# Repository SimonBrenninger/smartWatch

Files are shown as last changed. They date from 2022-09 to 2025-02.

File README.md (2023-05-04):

# smartWatch

is a simple, digital wristwatch that uses LEDs to indicate the position of each clock arm.

## Smart Features

The smartWatch incorporates an nRF52810 for handling BLE connectivity to send the monitored data regularly to the host device.

## PCB Design

The PCB was designed using [KiCad](https://kicad.org).

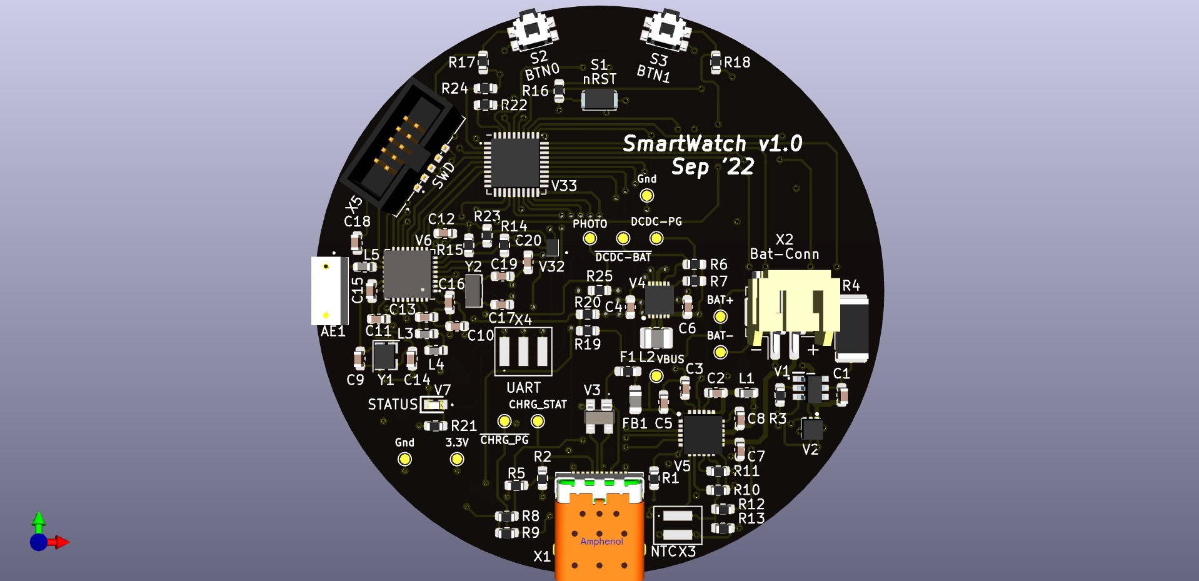
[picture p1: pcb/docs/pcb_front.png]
PCB render front-side

PCB front-side

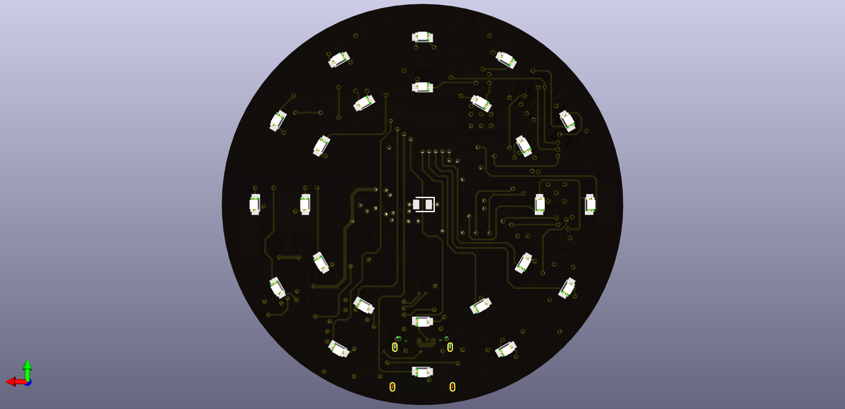
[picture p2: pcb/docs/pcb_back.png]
PCB render back-side

PCB back-side

## Future Features

A future revision will include a biomedical sensor to enable even more smart functionalities i.e. SpO2 and heart-rate measurements.

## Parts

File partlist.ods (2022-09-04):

smartWatch | BOM |  |  |  |  |  | 30cm pcb
Name | Qty | Mouser No: | Mfr. No: | Total Price | Datasheet | Alternatives
nRF52810 | 1 | 949-NRF52810-QFAA-T | nRF52810-QFAA-T (https://www.mouser.at/ProductDetail/Nordic-Semiconductor/nRF52810-QFAA-T?qs=gt1LBUVyoHlzDk3rt9zm6Q%3D%3D) | 3.33 | nRF52810-QFAA-T (https://www.mouser.at/datasheet/2/297/nRF52810_PB_v1.1-1146849.pdf)
Phototransistor | 1 | SFH 3710-Z | SFH 3710-Z (https://www.mouser.at/ProductDetail/ams-OSRAM/SFH-3710-Z?qs=K5ta8V%252BWhtbrxZMXxkWWCQ%3D%3D) | 0.9 | SFH 3710-Z (https://dammedia.osram.info/media/resource/hires/osram-dam-5961394/SFH%203710_EN.pdf)
I/O Expander | 1 | PCA9957HNMP | PCA9957HNMP (https://www.mouser.at/ProductDetail/NXP-Semiconductors/PCA9957HNMP?qs=Cb2nCFKsA8p1S9uEv3UAJg%3D%3D) | 2.61 | PCA9957HNMP (https://www.mouser.at/datasheet/2/302/PCA9957DS-1670403.pdf) |  | I2C (+INT) |  | INT any edge on any pin
Gyroscope | 1 | 438-MXC4005XC | MXC4005XC (https://www.mouser.at/ProductDetail/MEMSIC/MXC4005XC?qs=RcG8xmE7yp3iyYgWLmAtUw%3D%3D) | 1.42 | MXC4005XC (https://www.mouser.at/datasheet/2/821/Memsic_08302019_MXC400xXC_Datasheet_Rev_B-1892039.pdf) |  | I2C + INT |  | INT Shake-Detection
Protection | 1 | 621-AP9101CAK6ABTRG1 | AP9101CAK6-ABTRG1 (https://www.mouser.at/ProductDetail/Diodes-Incorporated/AP9101CAK6-ABTRG1?qs=W66WzN12R3Y9HS2QV9IuJA%3D%3D) | 0.44 | AP9101CAK6-ABTRG1 (https://www.mouser.at/datasheet/2/115/DIOD_S_A0007229744_1-2542938.pdf) | XB8089D
Charger | 1 | BQ25606RGET | BQ25606RGET (https://www.mouser.at/ProductDetail/Texas-Instruments/BQ25606RGET?qs=5aG0NVq1C4yFkgOQCbyUyg%3D%3D) | 3.99 | BQ25606RGET (https://www.ti.com/general/docs/suppproductinfo.tsp?distId=26&gotoUrl=https://www.ti.com/lit/gpn/bq25606) | BQ24092DGQR | CHG +PG |  | Charge done, power good
eFuse | 1 | 757-TCKE812NA,RF | TCKE812NA,RF (https://www.mouser.at/ProductDetail/Toshiba/TCKE812NARF?qs=7MVldsJ5UazIz%2F5VEH%2F60g%3D%3D) | 1.48 | TCKE812NA,RF (https://www.mouser.at/datasheet/2/408/TCKE812NA_datasheet_en_20210705-2509738.pdf) | TPS259621, 595-TPS25200QDRVRQ1
DC-DC | 1 | 968-ISL9110IRT7Z-T7A | ISL9110IRT7Z-T7A (https://www.mouser.at/ProductDetail/Renesas-Intersil/ISL9110IRT7Z-T7A) | 2.8 | ISL9110IRT7Z-T7A (https://www.mouser.at/datasheet/2/698/REN_isl9110_12_DST_20050421-1529440.pdf) | TPS61085DGKR | PG + BAT |  | Output & input power-good
ESD | 1 | 576-SP0503BAHTG | SP0503BAHTG (https://eu.mouser.com/ProductDetail/Littelfuse/SP0503BAHTG?qs=uD%2FdkN7XIa0NTYXwHdELYA%3D%3D) | 0.89 | SP0503BAHTG (https://eu.mouser.com/datasheet/2/240/Littelfuse_TVS_Diode_Array_SP05_Datasheet_pdf-777043.pdf)
LEDs green | 24 | 710-150080GS75000 | 150080GS75000 (https://www.mouser.at/ProductDetail/Wurth-Elektronik/150080GS75000?qs=2kOmHSv6VfQRoTEZVk1mGA%3D%3D) | 0.19 | 150080GS75000 (https://www.mouser.at/datasheet/2/445/150080GS75000-1715657.pdf)
LED red | 1 | 710-150060SS75003 | 150060SS75003 (https://www.mouser.at/ProductDetail/Wurth-Elektronik/150060SS75003?qs=Li%252BoUPsLEntNiRmIe%252Bnzlg%3D%3D) | 0.33 | 150060SS75003 (https://www.mouser.at/datasheet/2/445/150060SS75003-2907500.pdf)
MOSFET | 1 | 757-SSM6N68NULF | SSM6N68NU,LF (https://eu.mouser.com/ProductDetail/Toshiba/SSM6N68NULF?qs=wUXugUrL1qwp%2FrzVtV%2F87w%3D%3D) | 0.47 | SSM6N68NU,LF (https://eu.mouser.com/datasheet/2/408/SSM6N68NU_datasheet_en_20210107-1358562.pdf)
Thermistor NTC | 1 | 103AT-2 | 103AT-2 (https://www.mouser.at/ProductDetail/Semitec/103AT-2?qs=wgO0AD0o1vvcDzsKguD%252Bew%3D%3D) | 0.97 | 103AT-2 (https://www.mouser.at/datasheet/2/362/semitec_atthermistor-1202913.pdf)
USB-C | 1 | 12401598E4#2A | 12401598E4#2A (https://www.mouser.at/ProductDetail/Amphenol-Commercial-Products/12401598E42A?qs=367PjNmvCmllVMBVyIyS3w%3D%3D) | 1.58 | 12401598E4#2A (https://www.amphenol-icc.com/media/wysiwyg/files/documentation/datasheet/inputoutput/io_usb_type_c.pdf)
USB-Breakout |  |  | 4396 (https://www.mouser.at/ProductDetail/Adafruit/4396?qs=CUBnOrq4ZJwQuAtZPG3t1A%3D%3D) | 3.5
Antenna | 1 | NN01-102 | NN01-102 (https://www.mouser.at/ProductDetail/Ignion/NN01-102?qs=bAKSY%2FctAC74AFavC%252BjOHQ%3D%3D) | 0.68 | NN01-102 (https://www.mouser.at/datasheet/2/1029/Ignion_03262021_NN01_102-2255879.pdf) | https://www.ignion.io/files/UM_NN01-102.pdf
32MHz | 1 | ECS-320-8-36CKM-TR3 | ECS-320-8-36CKM-TR3 (https://www.mouser.at/ProductDetail/ECS/ECS-320-8-36CKM-TR3) | 0.36 | ECS-320-8-36CKM-TR3 (https://www.mouser.at/datasheet/2/122/ECX_2236-2497269.pdf)
32k | 1 | ECS-.327-9-34B-C-TR | ECS-.327-9-34B-C-TR (https://www.mouser.at/ProductDetail/ECS/ECS-.327-9-34B-C-TR?qs=wo4x%252BUeoG8W%2FQAwbzhP8Uw%3D%3D) | 0.78 | ECS-.327-9-34B-C-TR (https://www.mouser.at/datasheet/2/122/ecx-31b-1108368.pdf)
JST PH | 2 |  | S2B-PH-SM4 (https://lcsc.com/product-detail/Wire-To-Board-Wire-To-Wire-Connector_JST-Sales-America-S2B-PH-SM4-TB-LF-SN_C295747.html)
Health Sensor | 1 | 985-AS7038RB-COLM | AS7038RB-COLM (https://www.mouser.at/ProductDetail/ams/AS7038RB-COLM?qs=sPbYRqrBIVlfIQI2Rxv0lA%3D%3D) | 3.58 | AS7038RB-COLM (https://www.mouser.at/datasheet/2/588/AS7038RB_DS000726_2_00-1903063.pdf) |  | https://ams.com/documents/20143/36005/AS7038GB_AS7038RB_PD000546_1-00.pdf/9ac1d968-28da-d224-bd64-31765c393177
 |  |  |  |  |  |  | LTC3440EMS#TRPBF (https://www.mouser.at/ProductDetail/Analog-Devices/LTC3440EMSTRPBF?qs=hVkxg5c3xu9HFklrpLlQPw%3D%3D) | TPS54231DR (https://www.mouser.at/ProductDetail/Texas-Instruments/TPS54231DR?qs=XGzIaZb%2FFYKibJTOhGUd1A%3D%3D)
 |  | 0.2mm stencil

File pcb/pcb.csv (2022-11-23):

Source: | /home/simon/Documents/hardware_dev/projects/smartWatch/pcb/pcb.kicad_sch
Date: | Tue 01 Nov 2022 13:50:42 CET
Tool: | Eeschema 6.0.8+dfsg-1~bpo11+1
Generator: | /usr/share/kicad/plugins/bom_csv_grouped_by_value_with_fp.py
Component Count: | 108
Ref | Qnty | Value | Cmp name | Footprint | Description | Vendor
AE1, | 1 | Antenna_Chip | Antenna | myLib:Ignion_NN01-102_BT_WIFI | Antenna
C1, C11, C12, C16, | 4 | 100n | C_Small | Capacitor_SMD:C_0603_1608Metric | Unpolarized capacitor, small symbol
C2, C10, C20, | 3 | 4u7 | C_Small | Capacitor_SMD:C_0603_1608Metric | Unpolarized capacitor, small symbol
C3, C4, C6, C7, C8, | 5 | 10u | C_Small | Capacitor_SMD:C_0603_1608Metric | Unpolarized capacitor, small symbol
C5, C13, | 2 | 1u | C_Small | Capacitor_SMD:C_0603_1608Metric | Unpolarized capacitor, small symbol
C9, C14, C17, C19, | 4 | 12p | C_Small | Capacitor_SMD:C_0603_1608Metric | Unpolarized capacitor, small symbol
C15, | 1 | 100p | C_Small | Capacitor_SMD:C_0603_1608Metric | Unpolarized capacitor, small symbol
C18, | 1 | 0.8p | C_Small | Capacitor_SMD:C_0603_1608Metric | Unpolarized capacitor, small symbol
F1, | 1 | Fuse_1A | Fuse_Small | Fuse:Fuse_0603_1608Metric_Pad1.05x0.95mm_HandSolder | Fuse, small symbol
FB1, | 1 | FerriteBead_Small | FerriteBead_Small | Inductor_SMD:L_0805_2012Metric | Ferrite bead, small symbol
L1, | 1 | 1u | L_Small | Inductor_SMD:L_0603_1608Metric | Inductor, small symbol
L2, | 1 | 2u2 | L_Small | Inductor_SMD:L_1008_2520Metric | Inductor, small symbol
L3, | 1 | 15n | L_Small | Inductor_SMD:L_0603_1608Metric | Inductor, small symbol
L4, | 1 | 10u | L_Small | Inductor_SMD:L_0603_1608Metric | Inductor, small symbol
L5, | 1 | 3n9 | L_Small | Inductor_SMD:L_0603_1608Metric | Inductor, small symbol
R1, R2, | 2 | 5k11 | R_Small | Resistor_SMD:R_0603_1608Metric | Resistor, small symbol
R3, R25, | 2 | 2k7 | R_Small | Resistor_SMD:R_0603_1608Metric | Resistor, small symbol
R4, | 1 | 330R | R_Small | Resistor_SMD:R_2512_6332Metric | Resistor, small symbol
R5, | 1 | 0R | R_Small | Resistor_SMD:R_0603_1608Metric | Resistor, small symbol
R6, R7, R8, R9, R16, R17, R18, R24, | 8 | 10k | R_Small | Resistor_SMD:R_0603_1608Metric | Resistor, small symbol
R10, | 1 | 1k | R_Small | Resistor_SMD:R_0603_1608Metric | Resistor, small symbol
R11, | 1 | 820R | R_Small | Resistor_SMD:R_0603_1608Metric | Resistor, small symbol
R12, | 1 | 5k1 | R_Small | Resistor_SMD:R_0603_1608Metric | Resistor, small symbol
R13, | 1 | 30k | R_Small | Resistor_SMD:R_0603_1608Metric | Resistor, small symbol
R14, R15, R23, | 3 | 4k7 | R_Small | Resistor_SMD:R_0603_1608Metric | Resistor, small symbol
R19, | 1 | 33k | R | Resistor_SMD:R_0603_1608Metric | Resistor
R20, | 1 | 100k | R | Resistor_SMD:R_0603_1608Metric | Resistor
R21, | 1 | 330R | R | Resistor_SMD:R_0603_1608Metric | Resistor
R22, | 1 | 2k | R_Small | Resistor_SMD:R_0603_1608Metric | Resistor, small symbol
S1, | 1 | nRST | SW_DIP_x01 | myLib:SW_SPST_EVQP2 | 1x DIP Switch, Single Pole Single Throw (SPST) switch, small symbol
S2, | 1 | BTN0 | SW_DIP_x01 | myLib:Tactile_Panasonic_EVQP7J01P | 1x DIP Switch, Single Pole Single Throw (SPST) switch, small symbol
S3, | 1 | BTN1 | SW_DIP_x01 | myLib:Tactile_Panasonic_EVQP7J01P | 1x DIP Switch, Single Pole Single Throw (SPST) switch, small symbol
TP1, | 1 | 3.3V | TestPoint | TestPoint:TestPoint_Pad_D1.0mm | test point
TP2, TP6, | 2 | Gnd | TestPoint | TestPoint:TestPoint_Pad_D1.0mm | test point
TP3, | 1 | BAT+ | TestPoint | TestPoint:TestPoint_Pad_D1.0mm | test point
TP4, | 1 | BAT- | TestPoint | TestPoint:TestPoint_Pad_D1.0mm | test point
TP5, | 1 | VBUS | TestPoint | TestPoint:TestPoint_Pad_D1.0mm | test point
TP7, | 1 | ~{DCDC-BAT} | TestPoint | TestPoint:TestPoint_Pad_D1.0mm | test point
TP8, | 1 | DCDC-PG | TestPoint | TestPoint:TestPoint_Pad_D1.0mm | test point
TP9, | 1 | CHRG_STAT | TestPoint | TestPoint:TestPoint_Pad_D1.0mm | test point
TP10, | 1 | ~{CHRG_PG} | TestPoint | TestPoint:TestPoint_Pad_D1.0mm | test point
TP11, | 1 | PHOTO | TestPoint | TestPoint:TestPoint_Pad_D1.0mm | test point
V1, | 1 | AP9101CAK6-ABTRG1 | AP9101CAK6-ABTRG1 | Protection:SOT95P285X140-6N | Battery Management Protection IC 1-Cell LI 3.0uA 3.5V
V2, | 1 | SSM6N68NU,LF | SSM6N68NU,LF | Mosfet:SSM6N68NULF | MOSFET LowON Res MOSFET ID=4A VDSS=30V
V3, | 1 | SP0503BAHTG | SP0503BAHTG | ESD:SP0503BAHTG | ESD Suppressors / TVS Diodes TVS AVAL DIODE SMT
V4, | 1 | ISL9110IRT7Z-T7A | ISL9110IRT7Z-T7A | DC-DC:SON40P300X300X75-13N | Switching Voltage Regulators 1 2A SINGLE IND BUCK BOOST 3 3V 12LD
V5, | 1 | BQ25606RGET | BQ25606RGET | Charger:QFN50P400X400X100-25N | Stand Alone Single Cell 3-A Fast Charger with High Input Voltage and Power Path
V6, | 1 | nRF52810-QCxx | nRF52810-QCxx | Package_DFN_QFN:QFN-32-1EP_5x5mm_P0.5mm_EP3.6x3.6mm | Multiprotocol BLE/2.4GHz Cortex-M4 SoC, QFN-32
V7, | 1 | DBG_LED | 150060SS75000 | LED red:LEDC1608X80N | LED,Wurth Elektronik,150060SS75000 Wurth Elektronik 150060SS75000, WL-SMCW Series Red LED, 630 nm, 1608 (0603) Clear, Rectangle Lens SMD Package
V8, V9, V10, V11, V12, V13, V14, V15, V16, V17, V18, V19, V20, V21, V22, V23, V24, V25, V26, V27, V28, V29, V30, V31, | 24 | green | 150080GS75000 | LED green:LEDM2012X80N | 150080GS75000, Wurth Elektronik WL-SMCW 520 nm Green LED, 2012 (0805) Clear SMD package
V32, | 1 | MXC4005XC | MXC4005XC | Gyroscope:MXC4005XC | Accelerometers Monolithic and Wafer Level Packaged Three-Axis Accelerometer
V33, | 1 | PCA9957HNMP | PCA9957HNMP | Package_DFN_QFN:HVQFN-40-1EP_6x6mm_P0.5mm_EP4.1x4.1mm | LED Lighting Drivers I2C 5 V Constant Current LED Controller
V34, | 1 | SFH 3710 | Q_Photo_NPN | Phototransistor:LEDC2012X95N | NPN phototransistor, collector/emitter
X1, | 1 | USB_C_Receptacle_USB2.0 | USB_C_Receptacle_USB2.0 | myLib:USB_C_Receptacle_Amphenol_12401598 | USB 2.0-only Type-C Receptacle connector
X2, | 1 | Bat-Conn | Conn_01x02 | Connector_JST:JST_PH_B2B-PH-SM4-TB_1x02-1MP_P2.00mm_Vertical | Generic connector, single row, 01x02, script generated (kicad-library-utils/schlib/autogen/connector/)
X3, | 1 | NTC | Conn_01x02 | myLib:PinHeader_P2mm_1x02_SMD | Generic connector, single row, 01x02, script generated (kicad-library-utils/schlib/autogen/connector/)
X4, | 1 | UART | Conn_01x03 | myLib:PinHeader_P2mm_1x03_SMD | Generic connector, single row, 01x03, script generated (kicad-library-utils/schlib/autogen/connector/)
X5, | 1 | SWD | Conn_ARM_JTAG_SWD_10 | myLib:PinHeader_2x05_P1.27mm_Vertical_SMD | Cortex Debug Connector, standard ARM Cortex-M SWD and JTAG interface
Y1, | 1 | 32MHz | Crystal_GND24_Small | Crystal:Crystal_SMD_2520-4Pin_2.5x2.0mm | Four pin crystal, GND on pins 2 and 4, small symbol
Y2, | 1 | 32.768k | Crystal_Small | Crystal:Crystal_SMD_3215-2Pin_3.2x1.5mm | Two pin crystal, small symbol

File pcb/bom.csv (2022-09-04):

Item | Qty | Reference(s) | Value | Mouser Part Number | Total Qty
1 | 1 | AE1 | Antenna_Chip | NN01-102 | 3
2 | 4 | C1, C12, C13, C14 | 100n | 963-EMK107B7104KAHT | 12
3 | 3 | C2, C11, C19 | 4u7 | 81-GRM188Z71C475KE1J | 9
4 | 5 | C3, C4, C5, C6, C7 | 10u | 81-GRM188Z71A106KA3D | 15
5 | 1 | C8 | 1u | 187-CL10B105KO8NNND | 3
6 | 1 | C9 | 100p | 603-CC603JRNPO8BN101 | 3
7 | 4 | C10, C15, C16, C18 | 12p | 603-CC603GRNPO9BN120 | 12
8 | 1 | C17 | 0.8p | 791-0603N0R8C500CT | 3
9 | 1 | L1 | 1u | 810-TFM160808ALC1R0A | 3
10 | 1 | L2 | 2u2 | 739-MGV2520102R2M-10 | 3
11 | 1 | L3 | 15n | 609-L-14C15NKV4T | 3
12 | 1 | L4 | 10u | 810-MLZ1608M100WT000 | 3
13 | 1 | L5 | 3.9n | 81-LQW18AS3N9J00D | 3
14 | 2 | R1, R2 | 5k11 | 603-RC0603FR-105K11L | 6
15 | 2 | R3, R25 | 2k7 | 71-CRCW06032K70FKEAH | 6
16 | 1 | R4 | 330R | 71-CRCW0603330RFKEAH | 3
17 | 1 | R5 | 0R |  | 3
18 | 5 | R6, R7, R8, R9, R24 | 10k | 667-ERJ-3GEYJ103V | 15
19 | 1 | R10 | 1k | 603-AF0603JR-071KL | 3
20 | 1 | R11 | 820R | 603-AC0603JR-07820RL | 3
21 | 1 | R12 | 5k1 | 660-RK73B1JTTDD512J | 3
22 | 1 | R13 | 30k | 755-ESR03EZPJ303 | 3
23 | 3 | R14, R15, R23 | 4k7 | 660-RK73B1JTTD472J | 9
24 | 3 | R16, R17, R18 | 10k | 667-ERJ-3GEYJ103V | 9
25 | 1 | R19 | 33k | 603-RC0603JR-0733KL | 3
26 | 1 | R20 | 100k | 667-ERJ-3EKF1003V | 3
27 | 1 | R21 | 330R | 755-SDR03EZPJ331 | 3
28 | 1 | R22 | 2k | 791-WR06X2001FTL | 3
29 | 1 | S1 | nRST | 612-TL3780AF240QG | 3
30 | 1 | S2 | BTN0 | 667-EVQP7J01P | 3
31 | 1 | S3 | BTN1 | 667-EVQP7J01P | 3
44 | 1 | V1 | AP9101CAK6-ABTRG1 | 621-AP9101CAK6ABTRG1 | 3
45 | 1 | V2 | SSM6N68NU,LF | 757-SSM6N68NULF | 3
46 | 1 | V3 | SP0503BAHTG | 576-SP0503BAHTG | 3
47 | 1 | V4 | ISL9110IRT7Z-T7A | 968-ISL9110IRT7Z-T7A | 3
48 | 1 | V5 | BQ25606RGET | BQ25606RGET | 3
49 | 1 | V6 | nRF52810-QFxx | 949-NRF52810-QCAA-T | 3
50 | 1 | V7 | DBG_LED | 710-150060SS75000 | 3
51 | 24 | V8, V9, V10, V11, V12, V13, V14, V15, V16, V17, V18, V19, V20, V21, V22, V23, V24, V25, V26, V27, V28, V29, V30, V31 | green | 710-150080GS75000 | 48
52 | 1 | V32 | MXC4005XC | 438-MXC4005XC | 3
53 | 1 | V33 | PCA9957HNMP | PCA9957HNMP | 2
54 | 1 | V34 | SFH 3710 | SFH 3710-Z | 3
55 | 1 | X1 | USB_C_Receptacle_USB2.0 | 12401598E4#2A | 3
56 | 1 | X2 | Bat-Conn |  | 3
57 | 1 | X3 | NTC-Conn |  | 3
58 | 1 | X4 | SWD-Conn |  | 3
59 | 1 | X5 | UART_Conn |  | 3
60 | 1 | Y1 | 32MHz | ECS-320-8-36CKM-TR3 | 3
61 | 1 | Y2 | 32.768k | ECS-.327-9-34B-C-TR | 3

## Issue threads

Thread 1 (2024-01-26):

Implementing using CH582F chip

happytm, 2024-01-26:
Great project.

Is it possible to implement this using CH582F chip instead of NRF chip?

Thanks.

SimonBrenninger, 2024-01-28:
Hi,
I took a look at CH528F's datasheet, and the MCU looks like a great and cheap alternative to the nRF chip. As I used nearly all 32 GPIOs of the nRF5810, I would suggest to use its bigger brother CH582M, which has all 32 GPIOs broken out. Now, besides some minor track rerouting, I would say it is definitely possible to implement this project with an CH582 MCU.

However, I have to admit I couldn't find any infos about the CH582 currently being supported by the Zephyr RTOS. This means, you either have to port the software to CH582's own toolchain or you can check out the resources on porting a new MCU to Zephyr to be able to use the same codebase.

Hope that helps!

happytm, 2024-01-28:
Thank you for your response.

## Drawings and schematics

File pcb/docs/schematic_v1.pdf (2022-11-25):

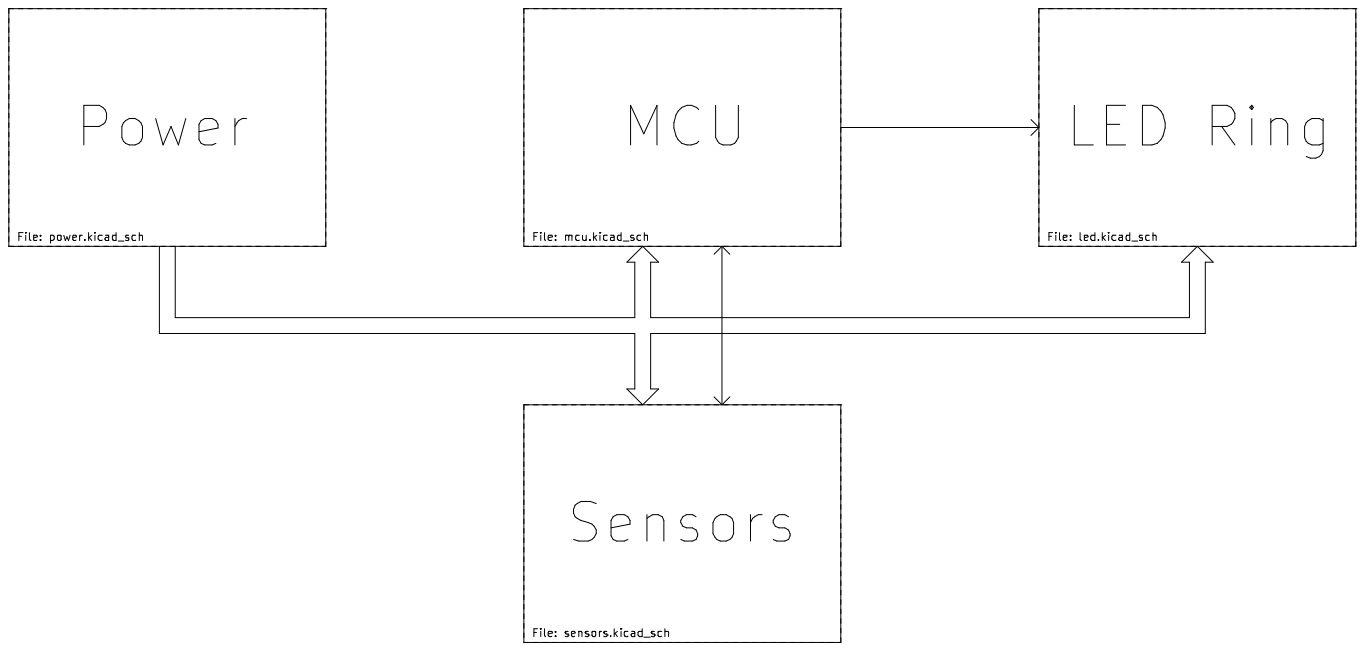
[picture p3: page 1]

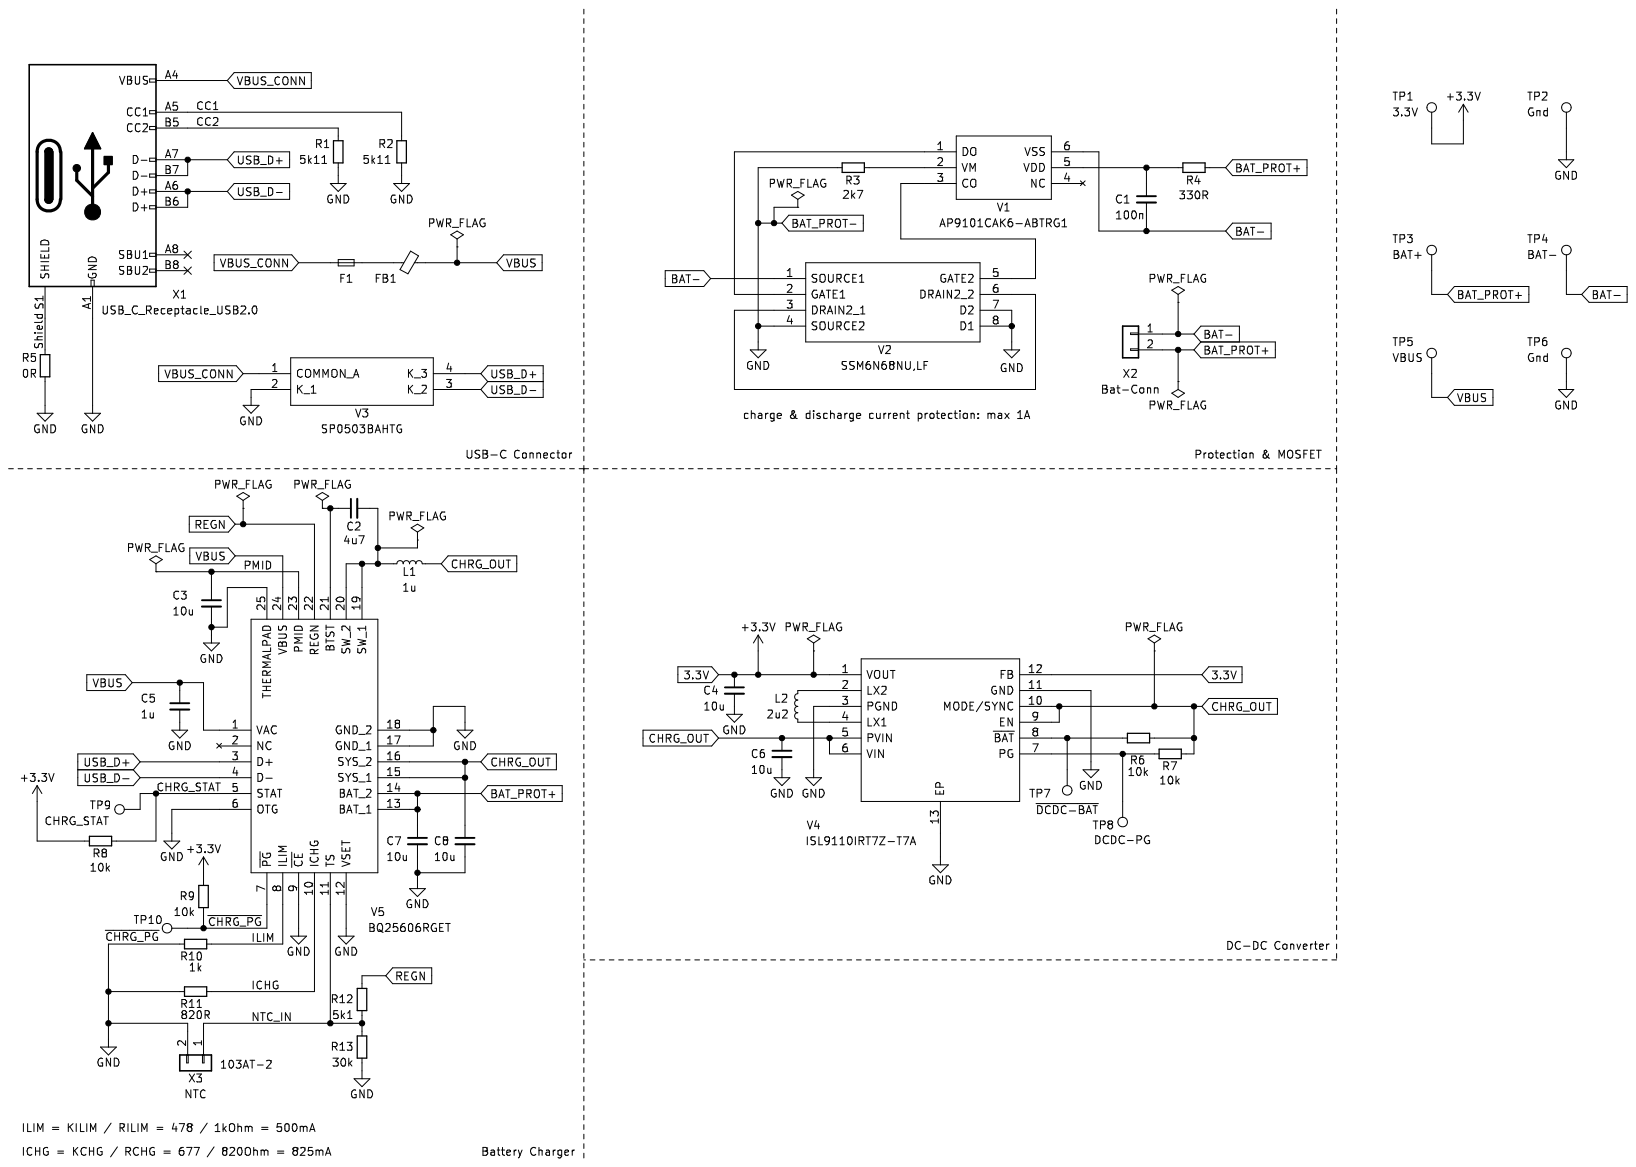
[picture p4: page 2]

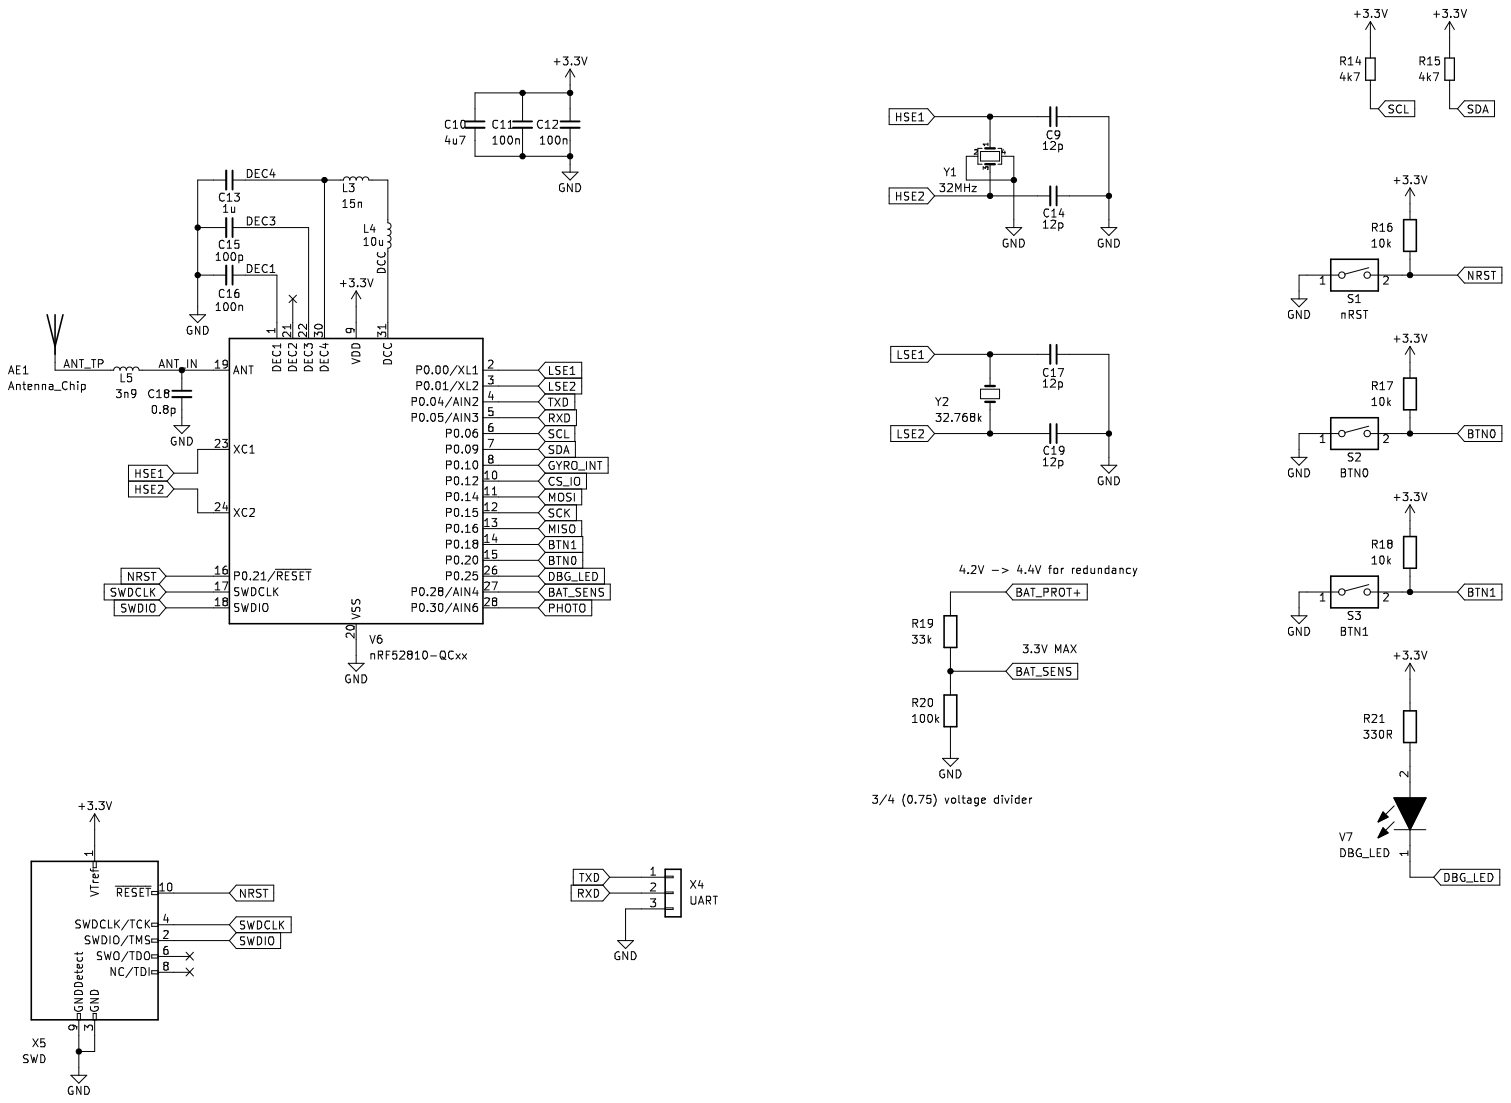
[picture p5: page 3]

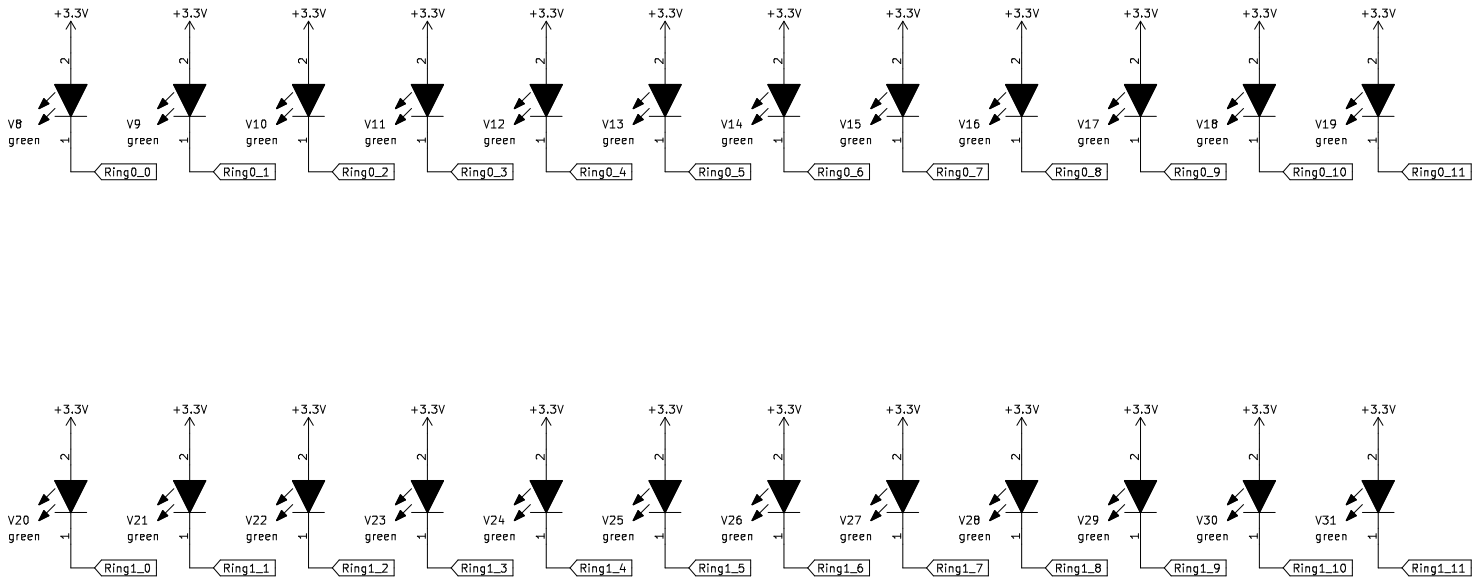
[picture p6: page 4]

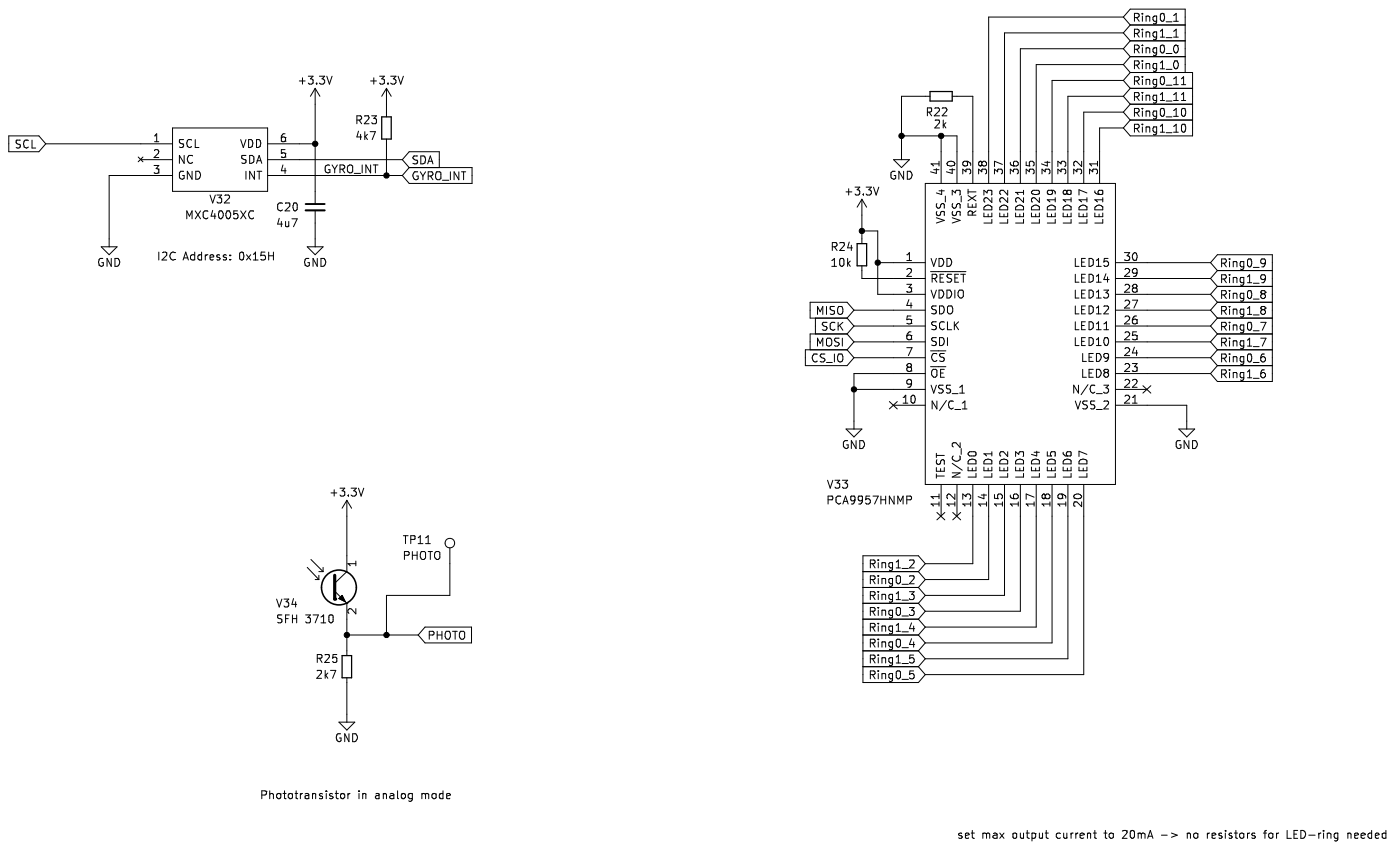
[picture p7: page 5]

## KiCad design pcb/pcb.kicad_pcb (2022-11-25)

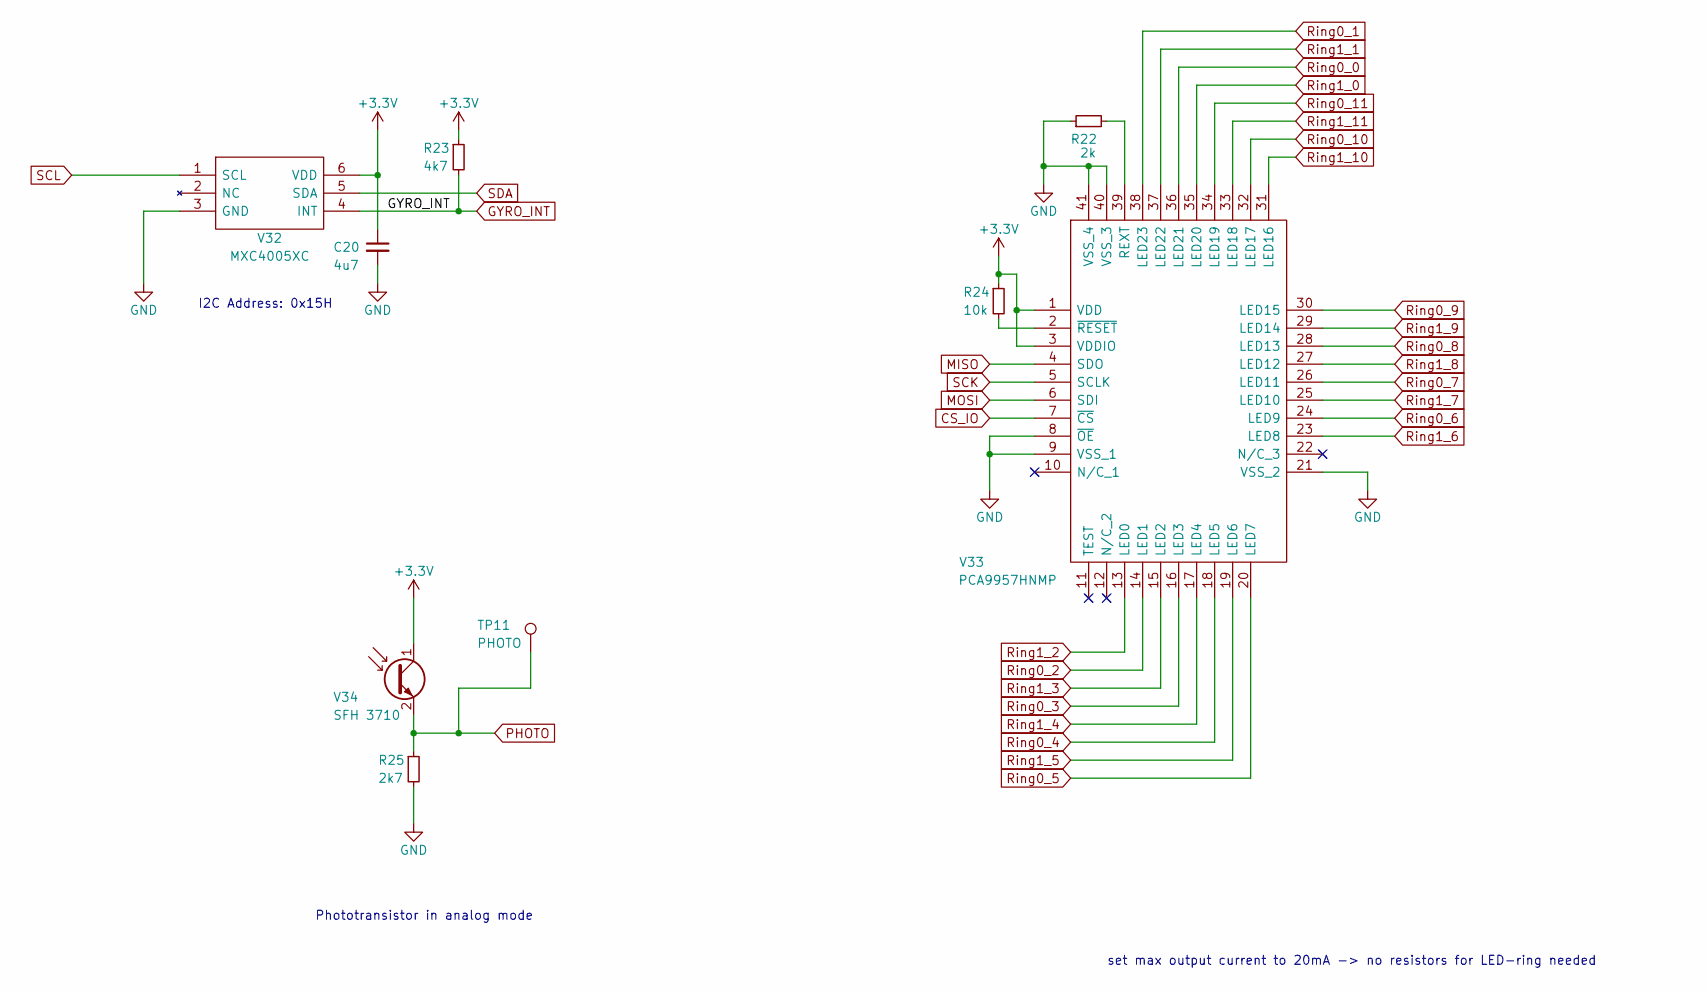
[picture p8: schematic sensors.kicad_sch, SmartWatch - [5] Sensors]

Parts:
C20: 4u7; C_0603_1608Metric
R22: 2k; R_0603_1608Metric
R23: 4k7; R_0603_1608Metric
R24: 10k; R_0603_1608Metric
R25: 2k7; R_0603_1608Metric
TP11: PHOTO; TestPoint_Pad_D1.0mm
V32: MXC4005XC; Mouser Part Number 438-MXC4005XC
V33: PCA9957HNMP; QFN-40-1EP_5x5mm_P0.4mm_EP3.6x3.6mm; Manufacturer_Part_Number PCA9957HNMP; Mouser Part Number PCA9957HNMP
V34: SFH 3710; LEDC2012X95N; Mouser Part Number SFH 3710-Z

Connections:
BAT_PROT-: C20.2, R22.1, R25.2, V32.3 (GND), V33.8 (~OE), V33.9 (VSS_1), V33.21 (VSS_2), V33.40 (VSS_3), V33.41 (VSS_4); also elsewhere on the board
CS_IO: V33.7 (~CS); also elsewhere on the board
GYRO_INT: R23.2, V32.4 (INT); also elsewhere on the board
MISO: V33.4 (SDO); also elsewhere on the board
MOSI: V33.6 (SDI); also elsewhere on the board
unnamed: R22.2, V33.39 (REXT)
unnamed: R24.2, V33.2 (~RESET)
PHOTO: R25.1, TP11.1, V34.2 (E); also elsewhere on the board
Ring0_0: V33.36 (LED21); also elsewhere on the board
Ring0_1: V33.38 (LED23); also elsewhere on the board
Ring0_2: V33.14 (LED1); also elsewhere on the board
Ring0_3: V33.16 (LED3); also elsewhere on the board
Ring0_4: V33.18 (LED5); also elsewhere on the board
Ring0_5: V33.20 (LED7); also elsewhere on the board
Ring0_6: V33.24 (LED9); also elsewhere on the board
Ring0_7: V33.26 (LED11); also elsewhere on the board
Ring0_8: V33.28 (LED13); also elsewhere on the board
Ring0_9: V33.30 (LED15); also elsewhere on the board
Ring0_10: V33.32 (LED17); also elsewhere on the board
Ring0_11: V33.34 (LED19); also elsewhere on the board
Ring1_0: V33.35 (LED20); also elsewhere on the board
Ring1_1: V33.37 (LED22); also elsewhere on the board
Ring1_2: V33.13 (LED0); also elsewhere on the board
Ring1_3: V33.15 (LED2); also elsewhere on the board
Ring1_4: V33.17 (LED4); also elsewhere on the board
Ring1_5: V33.19 (LED6); also elsewhere on the board
Ring1_6: V33.23 (LED8); also elsewhere on the board
Ring1_7: V33.25 (LED10); also elsewhere on the board
Ring1_8: V33.27 (LED12); also elsewhere on the board
Ring1_9: V33.29 (LED14); also elsewhere on the board
Ring1_10: V33.31 (LED16); also elsewhere on the board
Ring1_11: V33.33 (LED18); also elsewhere on the board
SCK: V33.5 (SCLK); also elsewhere on the board
SCL: V32.1 (SCL); also elsewhere on the board
SDA: V32.5 (SDA); also elsewhere on the board

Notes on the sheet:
set max output current to 20mA -> no resistors for LED-ring needed
I2C Address: 0x15H
Phototransistor in analog mode

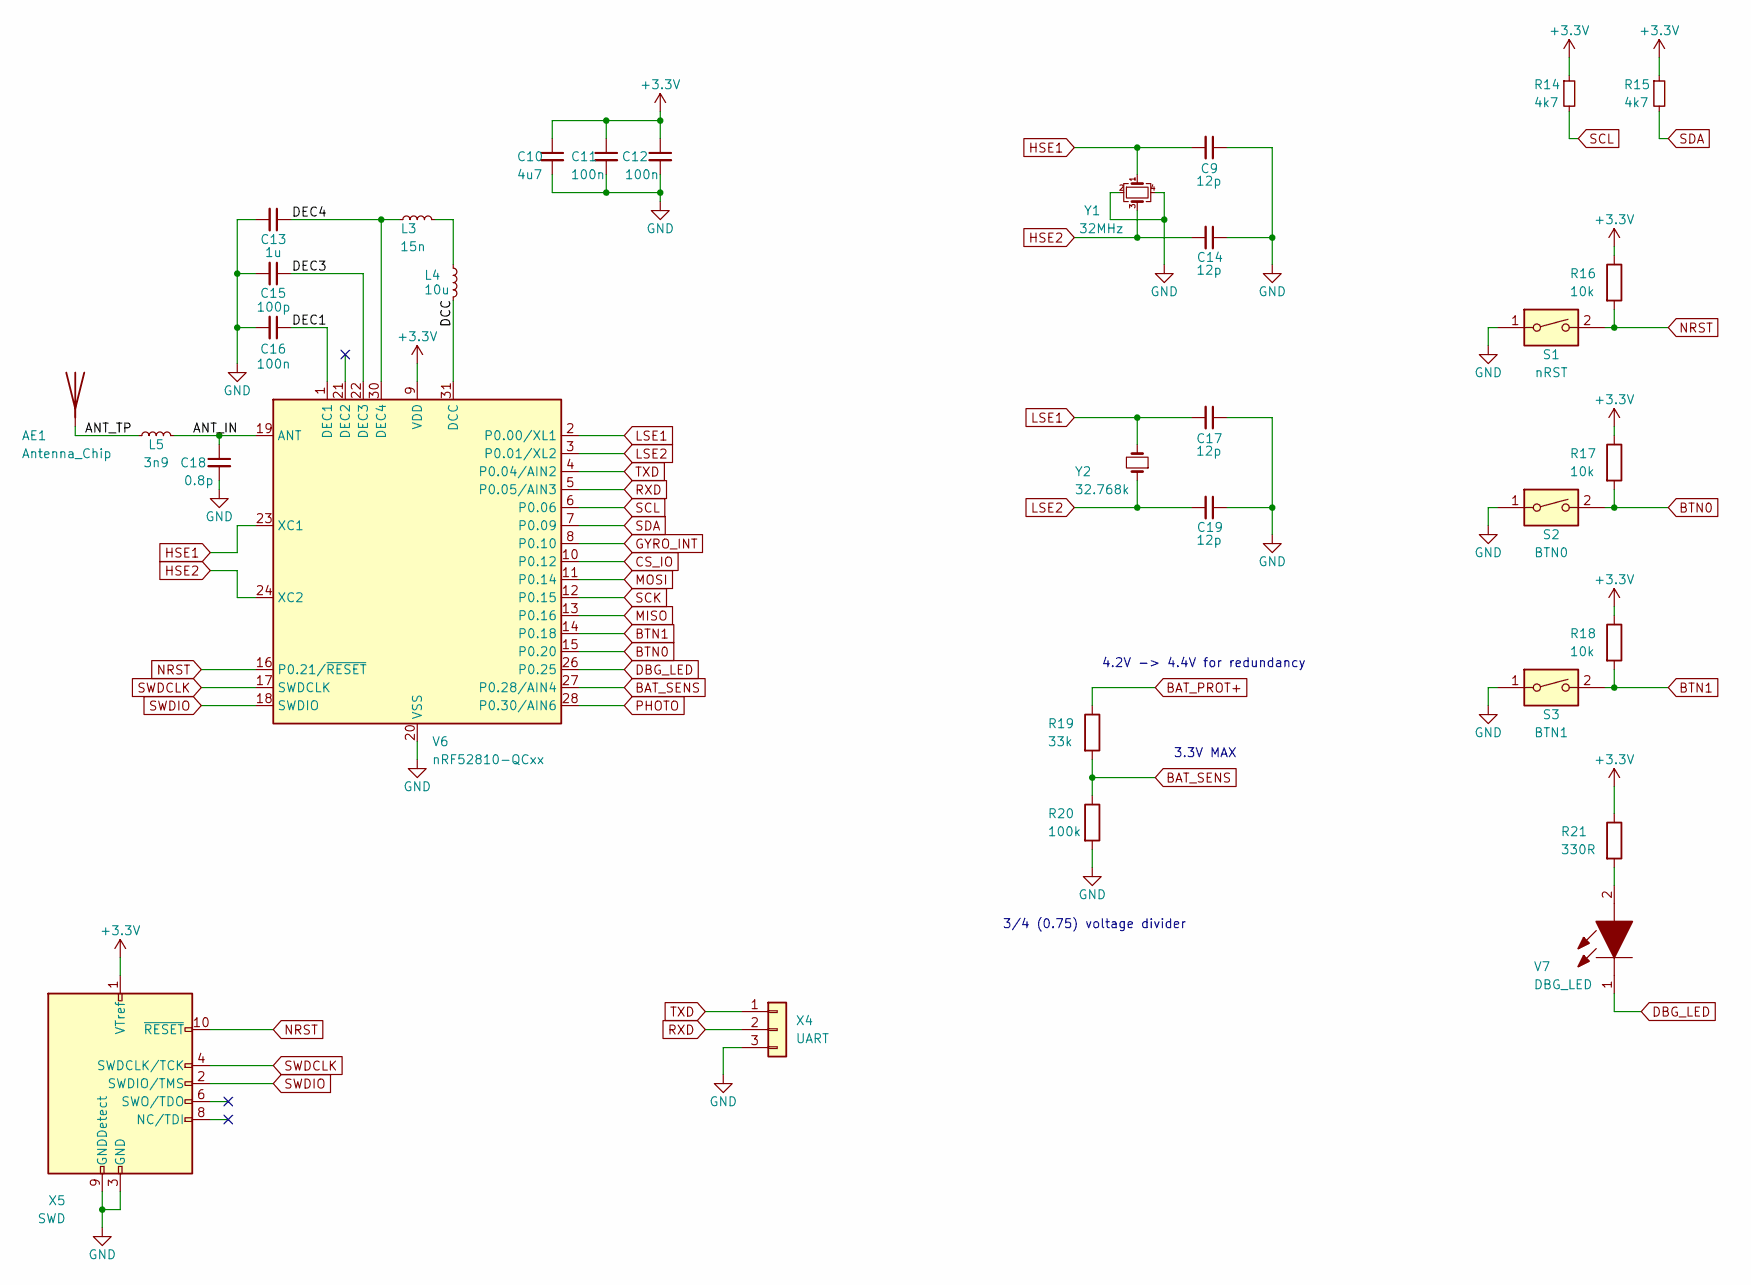
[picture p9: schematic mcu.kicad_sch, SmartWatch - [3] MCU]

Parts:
AE1: Antenna_Chip; Ignion_NN01-102_BT_WIFI
C9, C14, C17, C19: 12p; C_0603_1608Metric
C10: 4u7; C_0603_1608Metric
C11, C12, C16: 100n; C_0603_1608Metric
C13: 1u; C_0603_1608Metric
C15: 100p; C_0603_1608Metric
C18: 0.8p; C_0603_1608Metric
L3: 15n; L_0603_1608Metric
L4: 10u; L_0603_1608Metric
L5: 3n9; L_0603_1608Metric
R14, R15: 4k7; R_0603_1608Metric
R16, R17, R18: 10k; R_0603_1608Metric
R19: 33k; R_0603_1608Metric
R20: 100k; R_0603_1608Metric
R21: 330R; R_0603_1608Metric
S1: nRST; SW_SPST_EVQP2
S2: BTN0; Tactile_Panasonic_EVQP7J01P
S3: BTN1; Tactile_Panasonic_EVQP7J01P
V6: nRF52810-QCxx; QFN-32-1EP_5x5mm_P0.5mm_EP3.6x3.6mm
V7: DBG_LED; LEDC1608X80N; Mouser Part Number 710-150060SS75000
X4: UART; PinHeader_2x03_P1.27mm_Vertical_SMD
X5: SWD; PinHeader_2x05_P1.27mm_Vertical_SMD
Y1: 32MHz; Crystal_SMD_2520-4Pin_2.5x2.0mm; Mouser Part Number ECS-320-8-36CKM-TR3
Y2: 32.768k; Crystal_SMD_3215-2Pin_3.2x1.5mm; Mouser Part Number ECS-.327-9-34B-C-TR

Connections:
/MCU/ANT_IN: C18.1, L5.2, V6.19 (ANT)
/MCU/ANT_TP: AE1.1 (A), L5.1
/MCU/DCC: L4.1, V6.31 (DCC)
/MCU/DEC1: C16.1, V6.1 (DEC1)
/MCU/DEC3: C15.1, V6.22 (DEC3)
/MCU/DEC4: C13.1, L3.2, V6.30 (DEC4)
BAT_PROT+: R19.1; also elsewhere on the board
BAT_PROT-: C9.1, C10.2, C11.2, C12.2, C13.2, C14.1, C15.2, C16.2, C17.1, C18.2, C19.1, R20.2, S1.1, S2.1, S3.1, V6.20 (VSS), V6.29 (VSS), V6.33 (VSS), X4.3, X5.3 (GND), X5.5 (GND), X5.9 (GNDDetect), Y1.2, Y1.4; also elsewhere on the board
BAT_SENS: R19.2, R20.1, V6.27 (P0.28/AIN4)
BTN0: R17.2, S2.2, V6.15 (P0.20)
BTN1: R18.2, S3.2, V6.14 (P0.18)
CS_IO: V6.10 (P0.12); also elsewhere on the board
DBG_LED: V6.26 (P0.25), V7.1
GYRO_INT: V6.8 (P0.10); also elsewhere on the board
HSE1: C9.2, V6.23 (XC1), Y1.1
HSE2: C14.2, V6.24 (XC2), Y1.3
LSE1: C17.2, V6.2 (P0.00/XL1), Y2.2
LSE2: C19.2, V6.3 (P0.01/XL2), Y2.1
MISO: V6.13 (P0.16); also elsewhere on the board
MOSI: V6.11 (P0.14); also elsewhere on the board
NRST: R16.2, S1.2, V6.16 (P0.21/~RESET), X5.10 (~RESET)
unnamed: L3.1, L4.2
unnamed: R21.2, V7.2
PHOTO: V6.28 (P0.30/AIN6); also elsewhere on the board
RXD: V6.5 (P0.05/AIN3), X4.2
SCK: V6.12 (P0.15); also elsewhere on the board
SCL: R14.2, V6.6 (P0.06); also elsewhere on the board
SDA: R15.2, V6.7 (P0.09); also elsewhere on the board
SWDCLK: V6.17 (SWDCLK), X5.4 (SWDCLK/TCK)
SWDIO: V6.18 (SWDIO), X5.2 (SWDIO/TMS)
TXD: V6.4 (P0.04/AIN2), X4.1

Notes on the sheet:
4.2V -> 4.4V for redundancy
3/4 (0.75) voltage divider
3.3V MAX

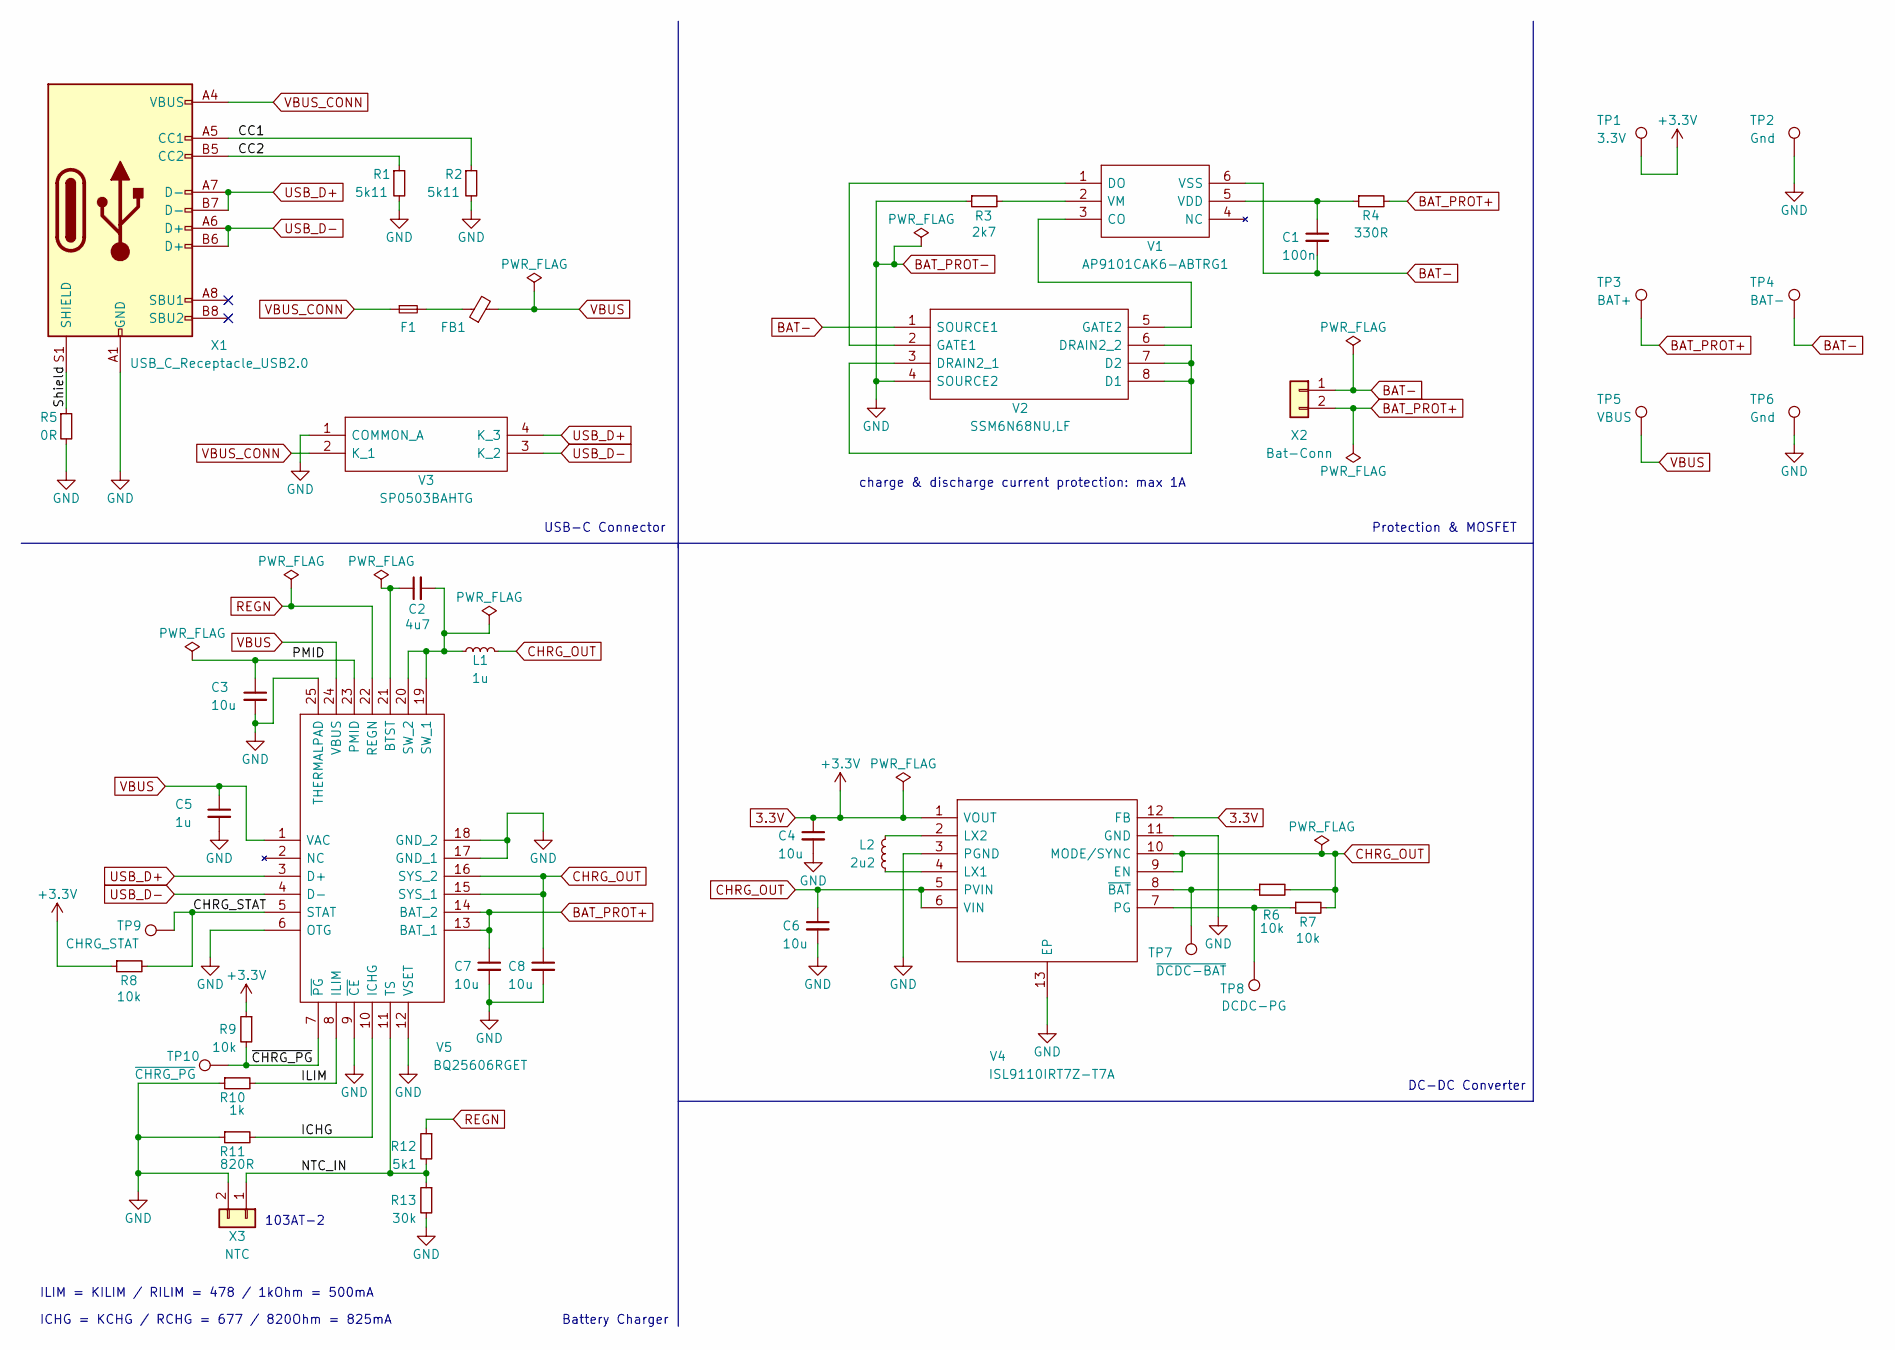
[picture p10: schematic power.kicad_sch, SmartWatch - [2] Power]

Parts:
C1: 100n; C_0603_1608Metric
C2: 4u7; C_0603_1608Metric
C3, C4, C6, C7, C8: 10u; C_0603_1608Metric
C5: 1u; C_0603_1608Metric
F1: Fuse_1A; Fuse_0603_1608Metric_Pad1.05x0.95mm_HandSolder
FB1: FerriteBead_Small; L_0805_2012Metric
L1: 1u; L_0603_1608Metric
L2: 2u2; L_1008_2520Metric
R1, R2: 5k11; R_0603_1608Metric
R3: 2k7; R_0603_1608Metric
R4: 330R; R_2512_6332Metric
R5: 0R; R_0603_1608Metric
R6, R7, R8, R9: 10k; R_0603_1608Metric
R10: 1k; R_0603_1608Metric
R11: 820R; R_0603_1608Metric
R12: 5k1; R_0603_1608Metric
R13: 30k; R_0603_1608Metric
TP1: 3.3V; TestPoint_Pad_D1.0mm
TP2, TP6: Gnd; TestPoint_Pad_D1.0mm
TP3: BAT+; TestPoint_Pad_D1.0mm
TP4: BAT-; TestPoint_Pad_D1.0mm
TP5: VBUS; TestPoint_Pad_D1.0mm
TP7: ~{DCDC-BAT}; TestPoint_Pad_D1.0mm
TP8: DCDC-PG; TestPoint_Pad_D1.0mm
TP9: CHRG_STAT; TestPoint_Pad_D1.0mm
TP10: ~{CHRG_PG}; TestPoint_Pad_D1.0mm
V1: AP9101CAK6-ABTRG1; SOT95P285X140-6N; Mouser Part Number 621-AP9101CAK6ABTRG1
V2: SSM6N68NU,LF; SSM6N68NULF; Manufacturer_Part_Number SSM6N68NU,LF; Mouser Part Number 757-SSM6N68NULF
V3: SP0503BAHTG; Manufacturer_Part_Number SP0503BAHTG; Mouser Part Number 576-SP0503BAHTG
V4: ISL9110IRT7Z-T7A; SON40P300X300X75-13N; Mouser Part Number 968-ISL9110IRT7Z-T7A
V5: BQ25606RGET; QFN50P400X400X100-25N; Mouser2 Part Number 595-BQ25606RGET
X1: USB_C_Receptacle_USB2.0; USB_C_Receptacle_Amphenol_12401598; Mouser Part Number 12401598E4#2A
X2: Bat-Conn; JST_PH_B2B-PH-SM4-TB_1x02-1MP_P2.00mm_Vertical
X3: NTC; PinHeader_P2mm_1x02_SMD

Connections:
/Power/CC1: R2.1, X1.A5 (CC1)
/Power/CC2: R1.1, X1.B5 (CC2)
/Power/CHRG_STAT: R8.2, TP9.1, V5.5 (STAT)
/Power/ICHG: R11.2, V5.10 (ICHG)
/Power/ILIM: R10.2, V5.8 (ILIM)
/Power/NTC_IN: R12.2, R13.1, V5.11 (TS), X3.1
/Power/PMID: C3.1, V5.23 (PMID)
/Power/Shield: R5.1, X1.S1 (SHIELD)
/Power/~CHRG_PG: R9.2, TP10.1, V5.7 (~PG)
BAT-: C1.2, TP4.1, V1.6 (VSS), V2.1 (SOURCE1), X2.1
BAT_PROT+: C7.1, R4.2, TP3.1, V5.13 (BAT_1), V5.14 (BAT_2), X2.2; also elsewhere on the board
BAT_PROT-: C3.2, C4.2, C5.2, C6.2, C7.2, C8.2, R1.2, R2.2, R3.1, R5.2, R10.1, R11.1, R13.2, TP2.1, TP6.1, V2.4 (SOURCE2), V3.1 (COMMON_A), V4.3 (PGND), V4.11 (GND), V4.13 (EP), V5.6 (OTG), V5.9 (~CE), V5.12 (VSET), V5.17 (GND_1), V5.18 (GND_2), V5.25 (THERMALPAD), X1.A1 (GND), X1.A12 (GND), X1.B1 (GND), X1.B12 (GND), X3.2; also elsewhere on the board
CHRG_OUT: C6.1, C8.1, L1.2, R6.2, R7.2, V4.5 (PVIN), V4.6 (VIN), V4.9 (EN), V4.10 (MODE/SYNC), V5.15 (SYS_1), V5.16 (SYS_2); also elsewhere on the board
unnamed: C1.1, R4.1, V1.5 (VDD)
unnamed: C2.1, V5.21 (BTST)
unnamed: C2.2, L1.1, V5.19 (SW_1), V5.20 (SW_2)
unnamed: F1.2, FB1.1
unnamed: L2.1, V4.2 (LX2)
unnamed: L2.2, V4.4 (LX1)
unnamed: R3.2, V1.2 (VM)
unnamed: R6.1, TP7.1, V4.8 (~BAT)
unnamed: R7.1, TP8.1, V4.7 (PG)
unnamed: V1.1 (DO), V2.2 (GATE1)
unnamed: V1.3 (CO), V2.5 (GATE2)
unnamed: V2.3 (DRAIN2_1), V2.6 (DRAIN2_2), V2.7 (D2), V2.8 (D1)
REGN: R12.1, V5.22 (REGN)
USB_D+: V3.4 (K_3), V5.3 (D+), X1.A7 (D-), X1.B7 (D-)
USB_D-: V3.3 (K_2), V5.4 (D-), X1.A6 (D+), X1.B6 (D+)
VBUS: C5.1, FB1.2, TP5.1, V5.1 (VAC), V5.24 (VBUS)
VBUS_CONN: F1.1, V3.2 (K_1), X1.A4 (VBUS), X1.A9 (VBUS), X1.B4 (VBUS), X1.B9 (VBUS)

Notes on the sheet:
ICHG = KCHG / RCHG = 677 / 820Ohm = 825mA
ILIM = KILIM / RILIM = 478 / 1kOhm = 500mA
DC-DC Converter
USB-C Connector
charge & discharge current protection: max 1A
Protection & MOSFET
103AT-2
Battery Charger

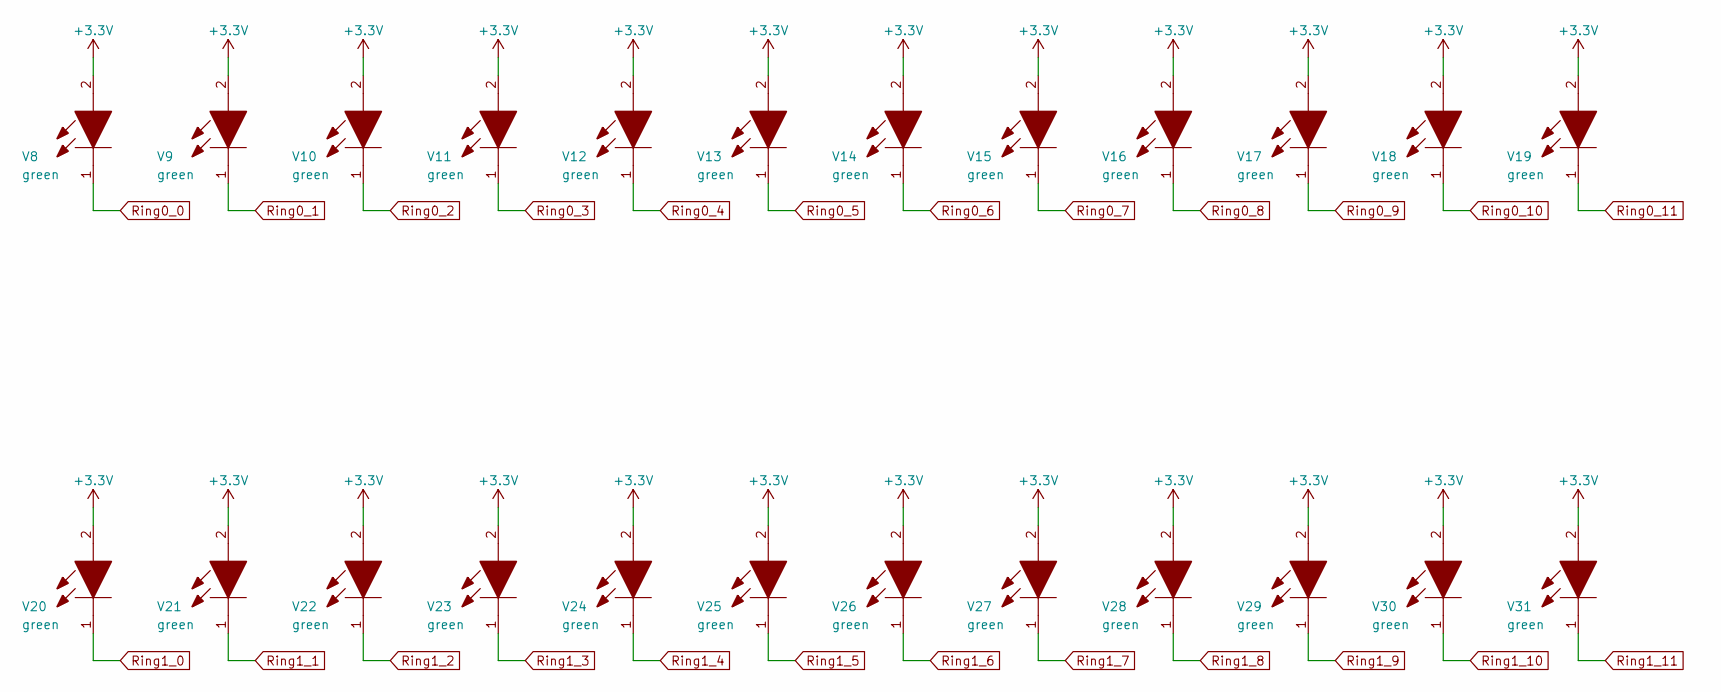
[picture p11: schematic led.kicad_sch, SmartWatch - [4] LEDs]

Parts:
V8, V9, V10, V11, V12, V13, V14, V15, V16, V17, V18, V19, V20, V21, V22, V23, V24, V25, V26, V27, V28, V29, V30, V31: green; LEDM2012X80N; Mouser Part Number 710-150080GS75000

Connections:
Ring0_0: V8.1; also elsewhere on the board
Ring0_1: V9.1; also elsewhere on the board
Ring0_2: V10.1; also elsewhere on the board
Ring0_3: V11.1; also elsewhere on the board
Ring0_4: V12.1; also elsewhere on the board
Ring0_5: V13.1; also elsewhere on the board
Ring0_6: V14.1; also elsewhere on the board
Ring0_7: V15.1; also elsewhere on the board
Ring0_8: V16.1; also elsewhere on the board
Ring0_9: V17.1; also elsewhere on the board
Ring0_10: V18.1; also elsewhere on the board
Ring0_11: V19.1; also elsewhere on the board
Ring1_0: V20.1; also elsewhere on the board
Ring1_1: V21.1; also elsewhere on the board
Ring1_2: V22.1; also elsewhere on the board
Ring1_3: V23.1; also elsewhere on the board
Ring1_4: V24.1; also elsewhere on the board
Ring1_5: V25.1; also elsewhere on the board
Ring1_6: V26.1; also elsewhere on the board
Ring1_7: V27.1; also elsewhere on the board
Ring1_8: V28.1; also elsewhere on the board
Ring1_9: V29.1; also elsewhere on the board
Ring1_10: V30.1; also elsewhere on the board
Ring1_11: V31.1; also elsewhere on the board

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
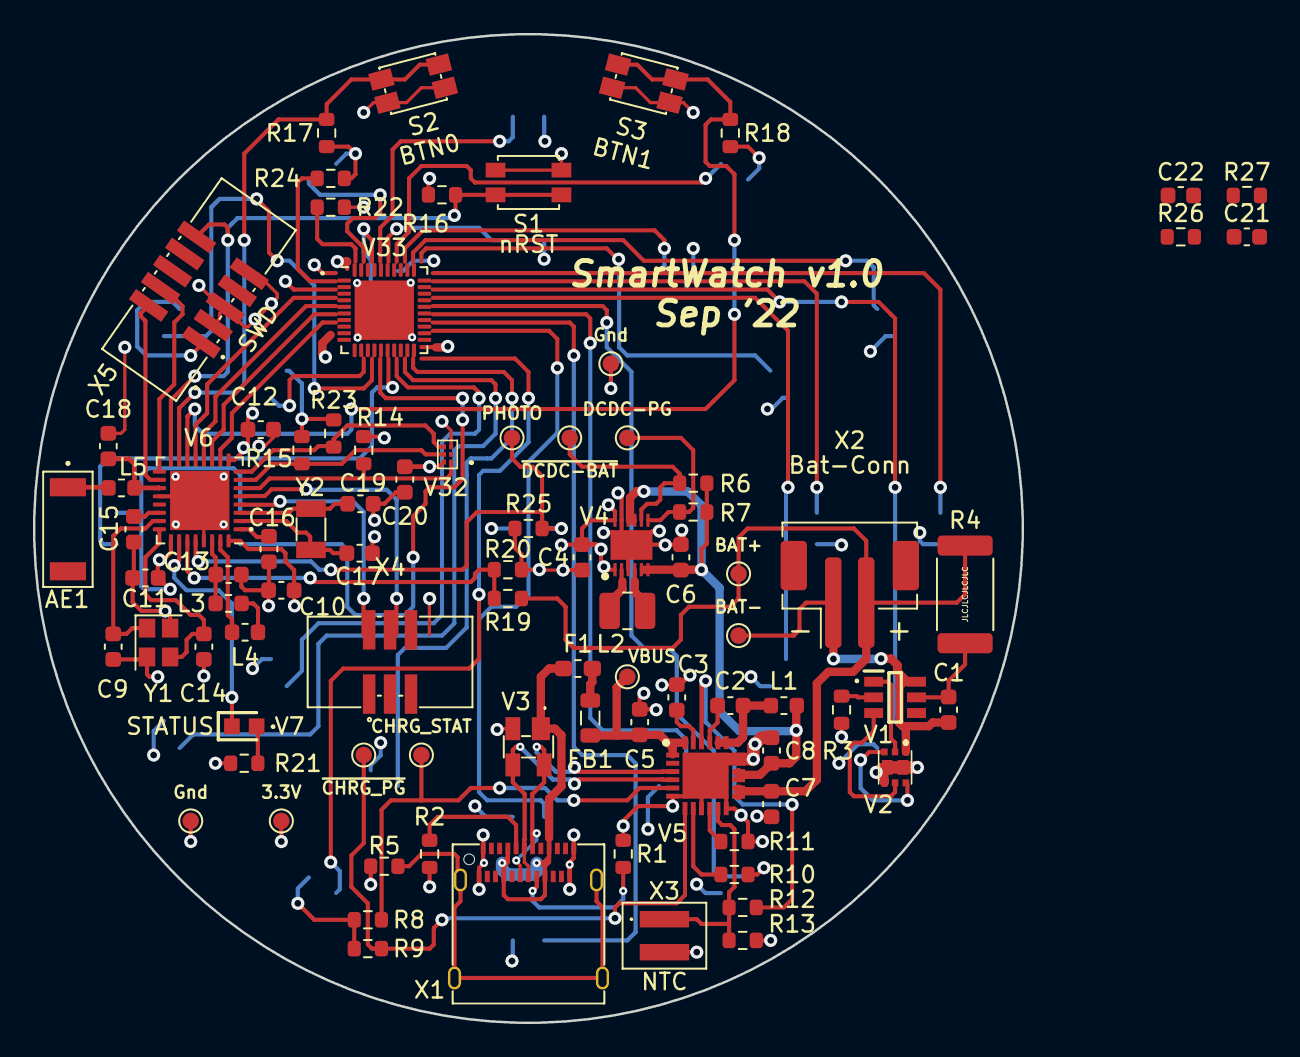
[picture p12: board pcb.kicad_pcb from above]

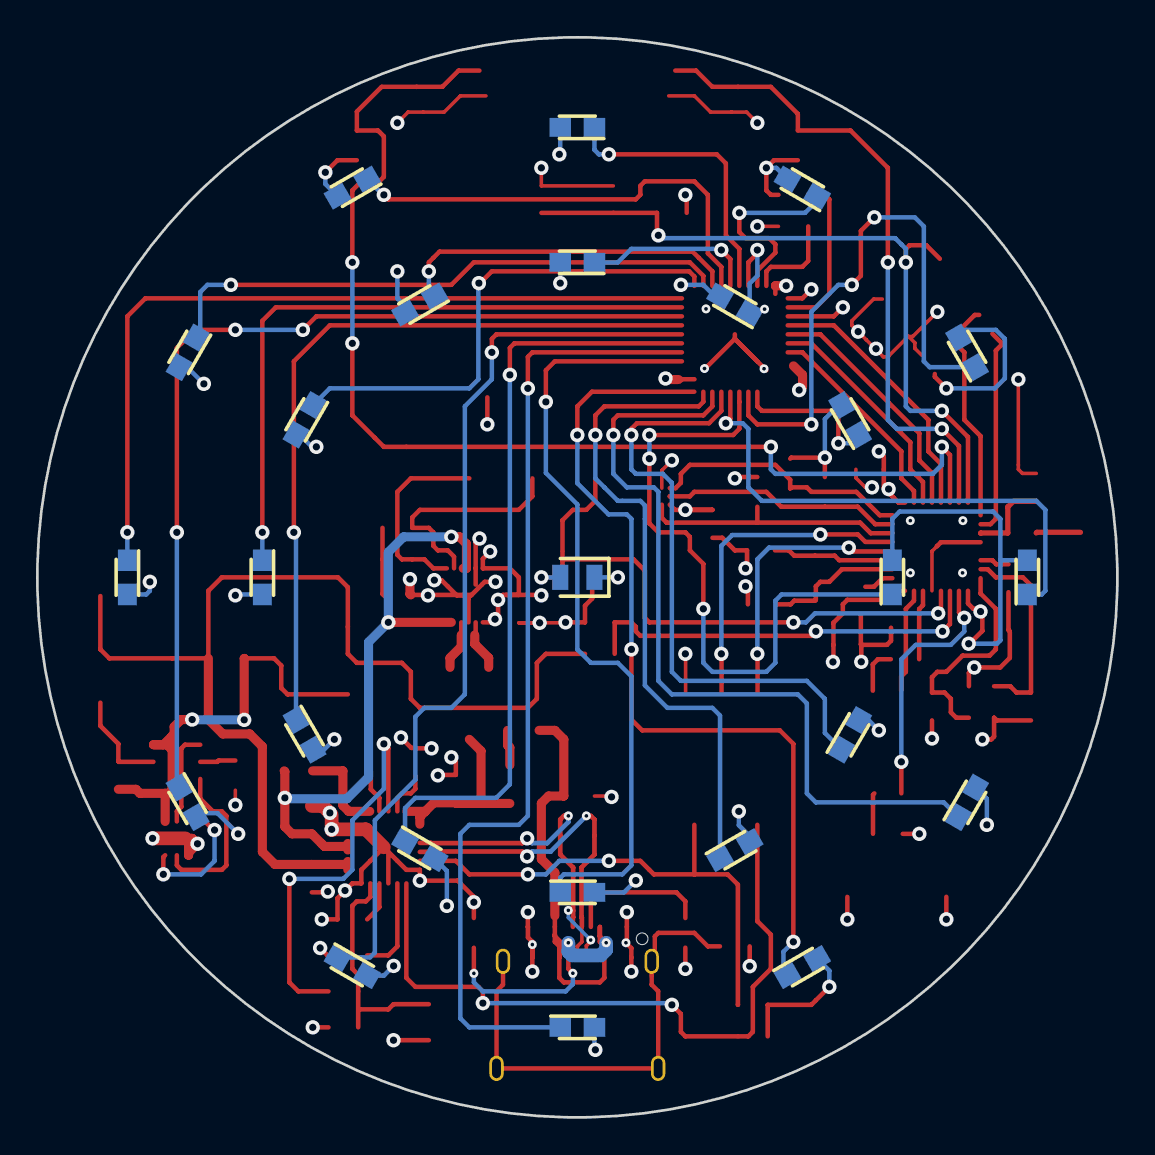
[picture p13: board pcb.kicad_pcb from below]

Board: 4 copper layers, 60.0 x 60.0 mm, 112 parts (25 on the bottom side), 87 nets.

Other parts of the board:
C21: 100n; C_0603_1608Metric
C22: 56p; C_0603_1608Metric
R26: 1Meg; R_0603_1608Metric
R27: 324k; R_0603_1608Metric

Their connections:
BAT_PROT-: C21.2, R27.1; also elsewhere on the board
CHRG_OUT: C21.1; also elsewhere on the board

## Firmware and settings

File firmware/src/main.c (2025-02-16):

/*
 * Copyright (c) 2025 Simon Brenninger
 * SPDX-License-Identifier: GPLv3
 */

#include <zephyr/kernel.h>
#include <zephyr/kernel/thread.h>
#include <zephyr/logging/log.h>
#include "lib/lib.h"

LOG_MODULE_REGISTER(SmartWatchDemo, LOG_LEVEL);

///*
K_THREAD_STACK_DEFINE(pca9957_stack, THREAD_STACK_SIZE);
K_THREAD_STACK_DEFINE(mxc400c_stack, THREAD_STACK_SIZE);
K_THREAD_STACK_DEFINE(rtc_stack, THREAD_STACK_SIZE);

k_tid_t pca9957_tid;
k_tid_t mxc400_tid;
k_tid_t adc_tid;
k_tid_t rtc_tid;

struct k_thread pca9957_thread_data;
struct k_thread mxc400_thread_data;
struct k_thread rtc_thread_data;
//*/


/**
 * @brief main thread
 */

int main(void)
{
	int ret;
	LOG_DBG("SmartWatch main thread");

	///*
	ret = gpio_init();
	ret |= adc_init();

	if(ret) {
		LOG_ERR("Error initializing periphs");
	} else {
		LOG_DBG("peripherals initialized");
		
		pca9957_tid = k_thread_create(&pca9957_thread_data, pca9957_stack,
									  K_THREAD_STACK_SIZEOF(pca9957_stack),
									  pca9957_thread,
									  NULL, NULL, NULL,
									  6, 0, K_NO_WAIT);
		
		mxc400_tid = k_thread_create(&mxc400_thread_data, mxc400c_stack,
									 K_THREAD_STACK_SIZEOF(mxc400c_stack),
									 mxc400_thread,
									 NULL, NULL, NULL,
									 6, 0, K_NO_WAIT);

		rtc_tid = k_thread_create(&rtc_thread_data, rtc_stack,
								  K_THREAD_STACK_SIZEOF(rtc_stack),
								  rtc_thread,
								  NULL, NULL, NULL,
								  5, 0, K_NO_WAIT);
	}
	//*/
	return 0;
}

/* 
 * application structure:
 * reset:
 * init peripherals
 * create threads:
 * - pca9957 thread:
 * 		init led driver
 * 		suspend and wait for notifications
 * 		when notified:
 * 			get brightness level
 * 			perform notified task
 * 			suspend
 * - mxc400 thread:
 * 		init interrupt callback
 * 		return
 * 		- callback:
 * 			reset pending interrupt flags
 * 			notify led driver to perform task
 * 			return
 * - rtc thread:
 * 		init rtc
 * 		init time
 * 		add timer callback (every sec)
 * 		return
 * 		callback:
 * 			update time
 * 			return
 *
 */

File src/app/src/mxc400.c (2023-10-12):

/*
 * Copyright (c) 2023 Simon Brenninger
 *
 * SPDX-License-Identifier: GPLv3
 */

#include "header.h"
#include "mxc400.h"

LOG_MODULE_DECLARE(SmartWatchDemo, LOG_LEVEL);

const struct device *i2c_dev = DEVICE_DT_GET(I2C_NODE);
const struct gpio_dt_spec mxc400_int = GPIO_DT_SPEC_GET(GYRO_INT_NODE, gpios);

static struct gpio_callback callback_data;
struct k_fifo pca_task_fifo;
static struct pca_task_el el;

void mxc400_callback(const struct device *dev, struct gpio_callback *cb, uint32_t pins) {
	//gpio_pin_toggle_dt(&led);
	k_fifo_put(&pca_task_fifo, &el);
}

/**
 * @brief mxc400 accelerometer thread
 */
void mxc400_thread(void *, void *, void *)
{
	int ret;
	LOG_DBG("MXC400 thread started");
	ret = mxc400_init();

	if(ret)
	{
		LOG_ERR("Error initializing MXC400");
		return;
	}
	LOG_DBG("MXC400 initialized");

	while(1)
	{
		k_sleep(K_FOREVER);
		mxc400_interrupt_clear(MXC400_INTFLAG_CHORXY);
	}
}

/*
reading device ID:

buf = 0x0E;
	ret = i2c_write(i2c_dev, &buf, 1, I2C_ADDRESS);
	if(ret != 0)
	{
		LOG_ERR("Error writing to I2C device\n");
		gpio_pin_set_dt(&led, 1);
		return;
	}

	ret = i2c_read(i2c_dev, &buf, 1, I2C_ADDRESS);
	if(ret != 0)
	{
		LOG_ERR("Error reading from I2C device\n");
		gpio_pin_set_dt(&led, 1);
		return;
	}

	if(buf != 0x02)
	{
		gpio_pin_set_dt(&led, 1);
		return;
	}

*/

/**
 * @brief initialize mxc400 accelerometer.
 * 
 * @retval 0 If successful.
 * @retval -errno Negative errno code on failure.
 */
int mxc400_init(void)
{
	int ret;

	if (!device_is_ready(mxc400_int.port) ||
		!device_is_ready(i2c_dev)) {
		return -1;
	}

	k_fifo_init(&pca_task_fifo);
	el.task = PCA9957_TASK_CLOCK;
	
	ret = gpio_pin_configure_dt(&mxc400_int, GPIO_INPUT);
	if (ret) { return ret; }
	ret = gpio_pin_interrupt_configure_dt(&mxc400_int, GPIO_INT_EDGE_FALLING);
	if (ret) { return ret; }
	gpio_init_callback(&callback_data, mxc400_callback, BIT(mxc400_int.pin));
	ret = gpio_add_callback(mxc400_int.port, &callback_data);
	if (ret) { return ret; }

	ret = mxc400_sw_reset();
	if (ret) { return ret; }

	ret = mxc400_interrupt_enable(MXC400_INTFLAG_CHORXY);
	return ret;
}

int mxc400_interrupt_enable(uint16_t intr_flags) {
	int ret;
	uint8_t buf[2];
	buf[0] = MXC400_INT_MASK0;
	buf[1] = (uint8_t) intr_flags;
	ret = i2c_write(i2c_dev, buf, 2, MXC400_ADDRESS);

	buf[1] = (uint8_t) (intr_flags >> 8);
	if(!ret && buf[1]) {
		buf[0] = MXC400_INT_MASK1;
		ret = i2c_write(i2c_dev, buf, 2, MXC400_ADDRESS);
	}
	return ret;
}

int mxc400_interrupt_clear(uint16_t intr_flags) {
	int ret;
	uint8_t buf[2];
	buf[0] = MXC400_INT_SRC0;
	buf[1] = (uint8_t) intr_flags;
	ret = i2c_write(i2c_dev, buf, 2, MXC400_ADDRESS);

	buf[1] = (uint8_t) (intr_flags >> 8);
	if(!ret && buf[1]) {
		buf[0] = MXC400_INT_SRC1;
		ret = i2c_write(i2c_dev, buf, 2, MXC400_ADDRESS);
	}
	return ret;
}

int mxc400_interrupt_pending(uint16_t *intr_flags) {
	int ret;
	uint8_t buf[4];
	struct i2c_msg msgs[4];
	buf[0] = MXC400_INT_SRC0;
	buf[2] = MXC400_INT_SRC1;

	msgs[0].buf = &buf[0];
	msgs[0].len = 1;
	msgs[0].flags = I2C_MSG_WRITE;

	msgs[0].buf = &buf[1];
	msgs[0].len = 1;
	msgs[0].flags = I2C_MSG_READ;

	msgs[1].buf = &buf[2];
	msgs[1].len = 1;
	msgs[1].flags = I2C_MSG_WRITE;

	msgs[1].buf = &buf[3];
	msgs[1].len = 1;
	msgs[1].flags = I2C_MSG_READ;

	ret = i2c_transfer(i2c_dev, msgs, 4, MXC400_ADDRESS);
	*intr_flags = (buf[3] << 8) & buf[1];
	return ret;
}

int mxc400_sw_reset(void) {
	int ret;
	uint8_t buf[2];
	buf[0] = MXC400_INT_CLR1;
	buf[1] = MXC400_INT_CLR1_SW_RST;

	ret = i2c_write(i2c_dev, buf, 2, MXC400_ADDRESS);
	return ret;
}

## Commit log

2022-09-04 add pcb cad project
    [biometrics.kicad_sch, g-sensor.kicad_sch, led.kicad_sch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]
2022-09-04 finish overview schematic page
    [biometrics.kicad_sch, g-sensor.kicad_sch, led.kicad_sch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]
2022-09-04 finish mcu connections
    [led.kicad_sch, mcu.kicad_sch, partlist.ods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]
2022-09-04 changed MCU package
    [mcu.kicad_sch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]
2022-09-04 add charging & preotection circuit
    [led.kicad_sch, mcu.kicad_sch, partlist.ods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]
2022-09-04 add dc-dc converter, add sensors
    [partlist.ods, pcb.kicad_sch, power.kicad_sch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]
2022-09-04 add LEDs for LED ring
    [led.kicad_sch, mcu.kicad_sch, partlist.ods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]
2022-09-04 add testpoints & connectors
    [led.kicad_sch, mcu.kicad_sch, partlist.ods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]
2022-09-04 add usb-c footprint
    [led.kicad_sch, mcu.kicad_sch, partlist.ods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]
2022-09-04 generate bom; select C's & L's
    [led.kicad_sch, mcu.kicad_sch, partlist.ods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]
2022-09-04 add pcb layout
    [bom.csv, mcu.kicad_sch, pcb.csv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]
2022-09-04 finish mcu section in pcb layout
    [pcb.kicad_pcb]
2022-09-04 add power section on pcb layout
    [led.kicad_sch, mcu.kicad_sch, pcb.kicad_pcb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]
2022-09-04 add back layer led-ring
    [mcu.kicad_sch, pcb.kicad_pcb, pcb.kicad_sch]
2022-09-04 finish back layer placement
    [pcb.kicad_pcb]
2022-09-04 route mcu section
    [pcb.kicad_pcb]
2022-09-06 add 3d models for pcb layout
    [led.kicad_sch, mcu.kicad_sch, pcb.kicad_pcb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]
2022-09-06 generate gerber files
    [pcb-B_Cu.gbr, pcb-B_Mask.gbr, pcb-B_Paste.gbr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]
2022-11-23 add features for v2 in pcb/todo
    [bom.csv, led.kicad_sch, mcu.kicad_sch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]
2022-11-23 add hvqfn adapter pcb
    [hvqfn_adapter.kicad_pcb, hvqfn_adapter.kicad_sch]
2022-11-23 add protection circuit measurements
2022-11-23 add zephyr board description
2022-11-25 add pcb fixes
    [mcu.kicad_sch, pcb.kicad_pcb, pcb.kicad_sch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]
2023-02-19 finish QFN adapter layout
    [hvqfn_adapter.kicad_pcb]
2023-02-19 add test application
    [ft2232_swd.cfg]
2023-02-19 change UART & SWD conn
2023-02-19 add led driver docs
2023-02-25 add datasheets
    [nrf52810_caaa.DRL, nrf52810_caaa.GBL, nrf52810_caaa.GBO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]
2023-04-21 edit gitignore
    [pcb.kicad_pcb, pcb.kicad_sch, power.kicad_sch]
2023-05-04 edit devicetree, change docs
2023-05-04 Revert "edit gitignore"
    This reverts commit 7d0c4b0df1450372f941e83b064acac36d25e600.
    [pcb.kicad_pcb, pcb.kicad_sch, power.kicad_sch]
2023-07-09 add rtc; re-organize dir
    [ft2232_swd.cfg]
2023-10-12 add pca thread queue
2024-01-29 rename firmware directory
    [ft2232_swd.cfg]
2025-02-16 update codebase to zephyr v4.0
    [ft2232-swd.cfg, ft2232_swd.cfg]
2025-02-16 remove kicad backup files
